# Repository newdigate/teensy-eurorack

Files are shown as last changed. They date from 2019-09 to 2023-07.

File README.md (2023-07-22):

# teensy eurorack audio shield 











Sponsored by:



**open source [hardware](hardware) and [software](https://github.com/newdigate/teensy-eurorack-software) for a 30-channel (14 in / 16 out) 16-bit analog [teensy 4.1](https://www.pjrc.com/store/teensy40.html "teensy 4.1 board") eurorack shield** 

* add peripherals to extend your [teensy 4.1](https://www.pjrc.com/store/teensy40.html "teensy 4.1 board") to interface with 
  * analog line audio (6 in / 8 out)
  * analog control voltages (8 in / 8 out: -10 to +10 volts)
  * midi in/out
  * microSD socket breakout
  * USB-A host and USB-B devices
  * 4 potentiometers, 3 encoders w/switch
* online designer [teensy eurorack audio gui](https://newdigate.github.io/teensy-eurorack-audio-gui) [^](https://github.com/newdigate/teensy-eurorack-audio-gui)

# updates 
  * 14 August 2021 : software and examples have moved to this repo [newdigate/teensy-eurorack-software](https://github.com/newdigate/teensy-eurorack-software)

# contents
* [sponsor](#sponsor)
* [specifications](#specifications)
* [license](#license)
* [open source software-stack](#open-source-software-stack)
* [build](#build)
  * [order pcbs](#order-pcbs)
  * [sourcing parts](#sourcing-parts)
    * [mouser boms](#mouser-boms)
    * [parts not on mouser boms](#parts-not-on-mouser-boms)
  * [interactive html boms online](#interactive-html-boms-online)
* [source code](#source-code)
* [improvements](#improvements)
* [printed circuit boards](#printed-circuit-boards)
  * [mainboard](#mainboard)
  * [breakout board](#breakout-board)
* [schematics](#schematics)  
* [panel design](#panel-design)  
* [assembly technical drawings](#assembly-technical-drawings)
* [youtube videos](#youtube-videos)
* [versions](#versions)
* [todo](#todo)
* [continuous-integration](#continuous-integration)
* [credits](#credits)
* [sponsored by](#sponsored-by)

# sponsor
* [patreon/teensy_eurorack](https://www.patreon.com/teensy_eurorack)
* paypal.me: [paypal.me/nicnewdigate](https://paypal.me/nicnewdigate)

# specifications
* **microcontrollers:** 
  * 600 Mhz ARM cortex m7 ( [teensy 4.1 board](https://www.pjrc.com/store/teensy41.html "teensy 4.1 board") )
* **audio:** multi-channel audio codec ( 6-in / 8-out 24-bit sound card - [CS42448](https://statics.cirrus.com/pubs/proDatasheet/CS42448_F5.pdf) )
  * *the audio codec circuit originally started as a discussion on quad audio channel outputs and a pcb design integrating teensy and cs42448 from Paul Stoffregen on [pjrc forum](https://forum.pjrc.com/threads/41371-Quad-channel-output-on-Teensy-3-6?p=138828&viewfull=1#post138828)*
* **analog control voltage ins/outs:** -10V to 10V 16bit/sample, 8 x inputs and 8 x outputs ( [ad7606](https://www.analog.com/media/en/technical-documentation/data-sheets/ad7606_7606-6_7606-4.pdf), 2x [ad5754](https://www.analog.com/media/en/technical-documentation/data-sheets/AD5724_5734_5754.pdf) )
* **display:** ST7735 128x128 16bit-color tft display
* **breakouts:** 
  * microSD card socket, 
  * USB host/device, 
  * midi in/out, 
  * knobs (4 x pots, 3 x encoders w/switch)
* **panel:** 24HP aluminium panel mounted for eurorack case
* **programability**: 
  * write arduino compatible c/c++ firmware & program using arduino/teensyduino
  * arm gnu toolchain [downloads](https://developer.arm.com/tools-and-software/open-source-software/developer-tools/gnu-toolchain/gnu-rm/downloads)
  * teensy [audio library](https://www.pjrc.com/teensy/gui/)

# license
* All artifacts are MIT license unless otherwise specified on a per file basis.

# open source software stack
* All [schematics](hardware/CIRCUITS.md) and boards are created using [Kicad](https://kicad.org/) 
* All mechanical designs are created using [FreeCAD](https://github.com/FreeCAD/FreeCAD)
* Some images have been rendered using [Blender 2.81](https://www.blender.org/)

# build
## order pcbs
* Use these gerber files to order 3 pcboards
  * the uSD-card extender should be about 0.6mm - 0.8mm thick
  * if you're using solder paste, you'll need to order the stencils of the bottom-side of main- and breakout boards.   
  
* [gerbers-breakout.zip](https://github.com/newdigate/teensy-eurorack/raw/master/hardware/gerbers/gerbers-breakout.zip)
* [gerbers-mainboard.zip](https://github.com/newdigate/teensy-eurorack/raw/master/hardware/gerbers/gerbers-mainboard.zip)
* [gerbers-uSD_extender_male.zip](https://github.com/newdigate/teensy-eurorack/raw/master/hardware/gerbers/gerbers-uSD_extender_male.zip)

## sourcing parts
Most parts are available from mouser.com - you can use the mouser BOMs below as a template to create an order. 

### mouser boms
* [mainboard](https://eu.mouser.com/ProjectManager/ProjectDetail.aspx?AccessID=e554cc1725)
* [breakoutboard](https://www.mouser.com/ProjectManager/ProjectDetail.aspx?AccessID=76e89a9e69)
### parts not on mouser boms
* panel: 
  * order from Front Panel Express: [.fpd](https://github.com/newdigate/teensy-eurorack/tree/master/hardware/panel/fpd)
    * for US: download [Front Panel Express](https://www.frontpanelexpress.com)
    * for Europe: download [Front Panel Designer](https://www.schaeffer-ag.de/en/front-panel-designer)
  * CNC your own with [FreeCad](https://www.freecadweb.org/downloads.php): [panel.FCStd](https://github.com/newdigate/teensy-eurorack/blob/master/hardware/panel/panel.FCStd) 
* mainboard:
  * 2.54mm pitch pin headers and sockets
    * J28: Eurorack power header: either male or female (2 x 8), I use female as my eurorack power (tip top) has male connectors. 
* breakout:
  * uSD card socket: [pjs008u-3000-0 yamaichi](https://octopart.com/pjs008u-3000-0-yamaichi-20649952?r=sp)
  * display: ST7735 (1.44 inch TFT LCD ST7735 SPI display module 128*128 8pin 65K color)

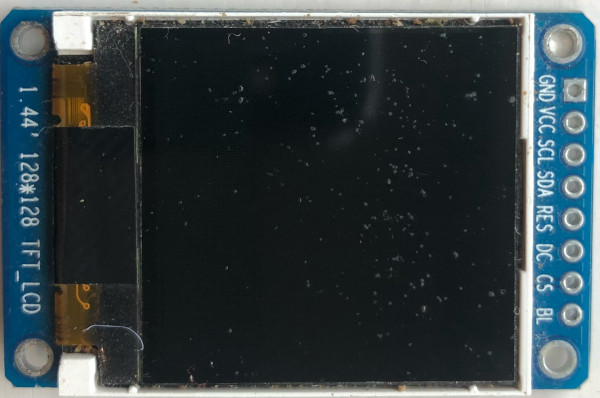
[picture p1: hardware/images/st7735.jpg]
    
    
  * 16 x thonkiconns: [PJ398SM](https://www.thonk.co.uk/shop/thonkiconn)
  * 4 x 9mm snap-in pots: [alpha-9mm-pots](https://www.thonk.co.uk/shop/alpha-9mm-pots/) - You want linear (B-series) not audio (A-series) B5K or B10K should be ideal.
  * 3 x rotary encoders w/switches: Half axis (D-shaft) rotary encoder, handle/axis length: 20mm, EC11/EC12 digital potentiometer with switch - 5Pin

**Update**: USB-A-S-X-X-VT is no longer available. [Amphenol Commercial Products GSB11111ALF](https://mou.sr/3OmC2OO) looks like it may be a good replacement.

## interactive html boms online
  * [mainboard](https://newdigate.github.io/teensy-eurorack/teensy-eurorack)
  * [breakoutboard](https://newdigate.github.io/teensy-eurorack/teensy-eurorack-breakout)

# source code
 * Teensy Audio library drivers for ad5754, ad7606 via SPI
   * [teensy-audio-ad5754-ad7606](https://github.com/newdigate/teensy-audio-ad5754-ad7606)
 * simple standard midi file reader 
   * [midi-smf-reader](https://github.com/newdigate/midi-smf-reader)
 * generic sequencer
   * [teensy-quencer](https://github.com/newdigate/teensy-quencer)
 * variable rate playback
   * [teensy-variable-playback](https://github.com/newdigate/teensy-variable-playback)
 * oscilliscope and x/y scope display components
   * [teensy-audio-libtftscope](https://github.com/newdigate/teensy-audio-libtftscope)
 * cmake macros for compiling c++ for arm cortex 
   * [teensy-cmake-macros](https://github.com/newdigate/teensy-cmake-macros)
 * Audio level and CV level meters 
   * [teensy-audio-display-components](https://github.com/newdigate/teensy-audio-display-components)

# improvements
At this point Im just focusing on finalising/polishing the current version, but there are some improvements I'd like to make at some point.
* add 4x jack sockets for analog output of knobs on breakout board. 
* use 3.5mm jack sockets (as well as standard midi din connectors) for midi in and out. 
* switch to active audio input and output circuitry, allow switchable 0dB / 12dB gain, for guitar signals.
* let me know if you're think there something else that can be improved, added, removed. 

There is a journal of my progress (its a bit out of date, sorry) - [journal.md](hardware/JOURNAL.md) 

**What you can do if you like to see progress with this project?**
* [#sponsor](#sponsor)...
* star this repository (means you need a github account - go for it!!)
* subscribe [Nic N on youtube](https://www.youtube.com/channel/UChMicDp8wUXYzBhEN-Wvb5g) 
* download kicad and freecad, clone this repo, make improvements, commit & send pull-requests, and raise issues...

# printed circuit boards
## [mainboard](hardware/boards/mainboard) 
* standard double layer printed circuit board
  * thinkness: 1.6mm  
  * minimum trace: 6 mil
  * minimum clearance: 6 mil
  * dimension: 118mm*102mm
* socket to connect teensy 4.0 board
* cs42448 audio codec 
* 3 x stereo 6.35mm TRS jack inputs
* 4 x stereo 6.35mm TRS jack outputs
* pin sockets to connect breakout board

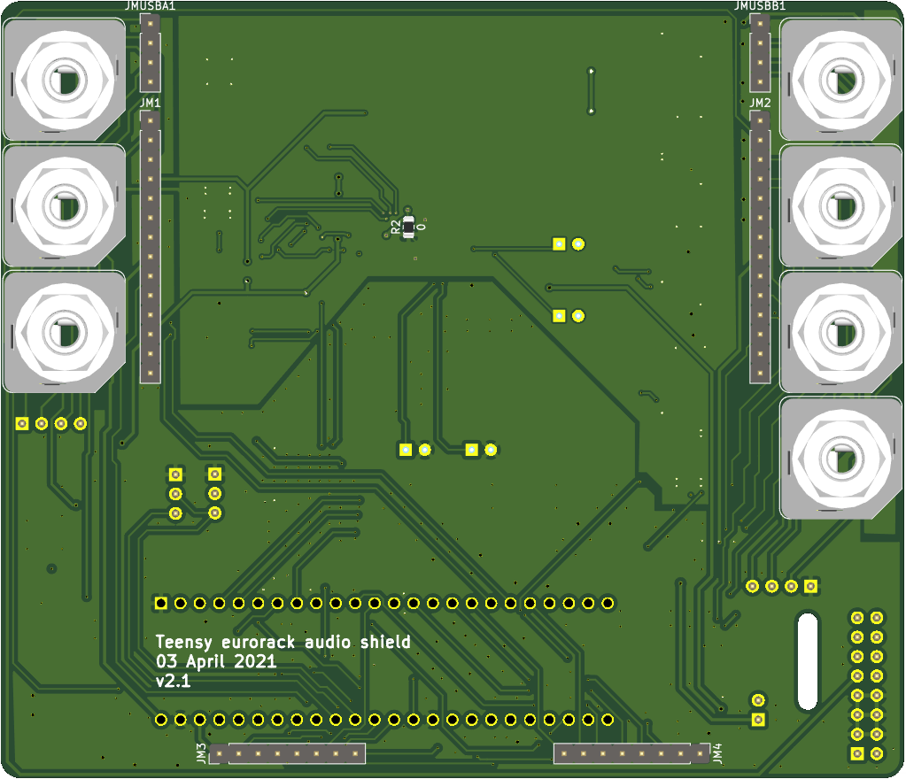
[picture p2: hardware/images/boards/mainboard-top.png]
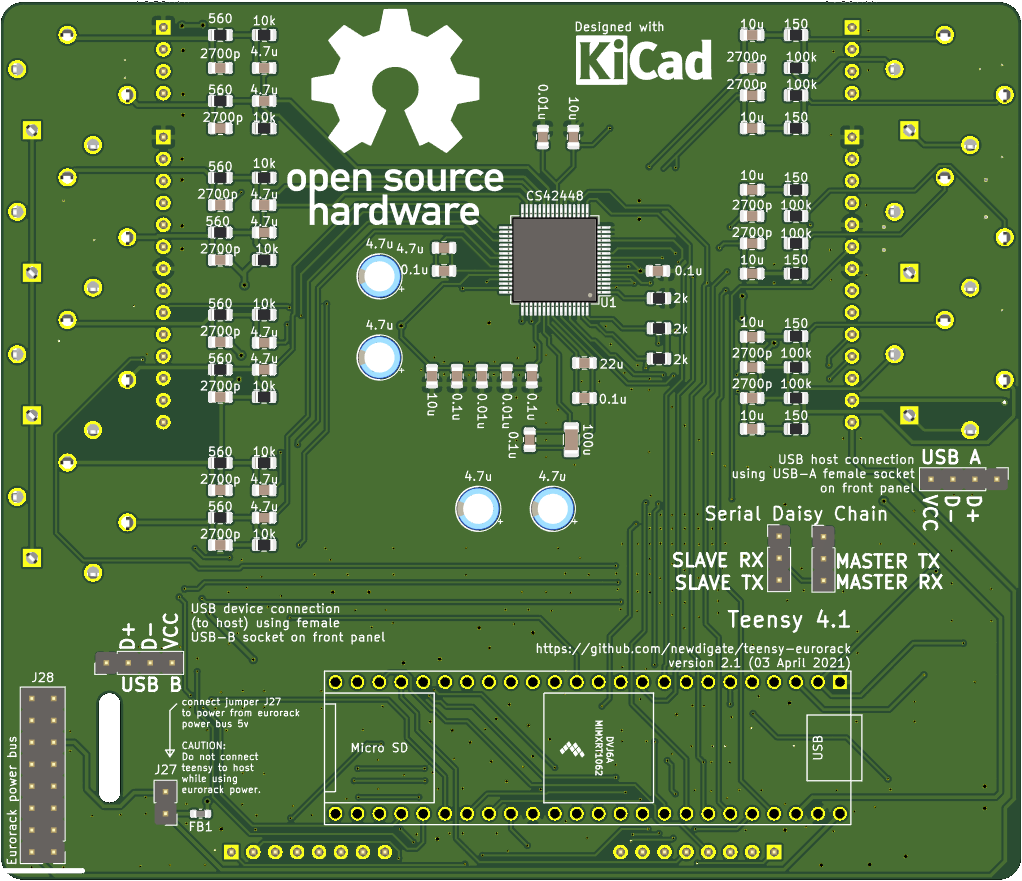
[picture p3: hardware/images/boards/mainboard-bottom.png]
  

## breakout board
* 2 layer printed circuit board
  * thinkness: 1.6mm  
  * minimum trace: 6 mil
  * minimum clearance: 6 mil
  * dimension: 110mm*111mm
* 8 x 3.5mm jack socket for analog control voltage inputs
* 8 x 3.5mm jack socket for analog control voltage outputs
* midi in/out DIN sockets
* usb device/host
  * USB-B: USB device mode
  * USB-A: USB host mode
* micro-SD card socket
* 4 x linear pots
* 3 x rotary encoders with switches 

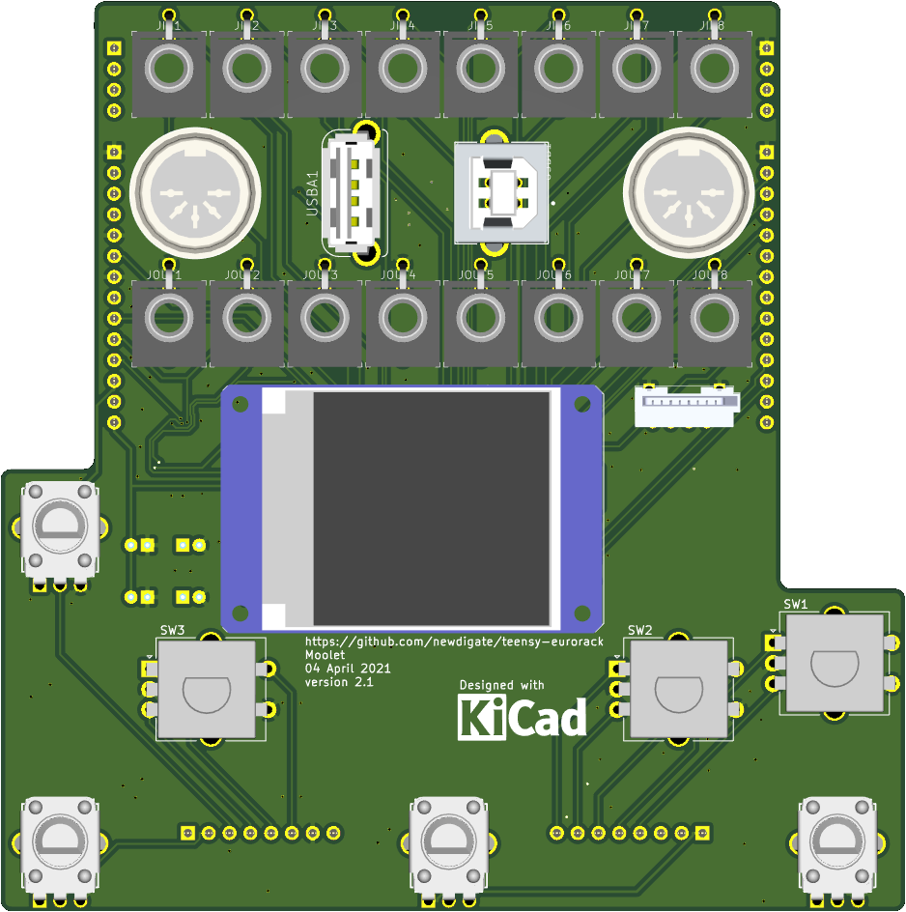
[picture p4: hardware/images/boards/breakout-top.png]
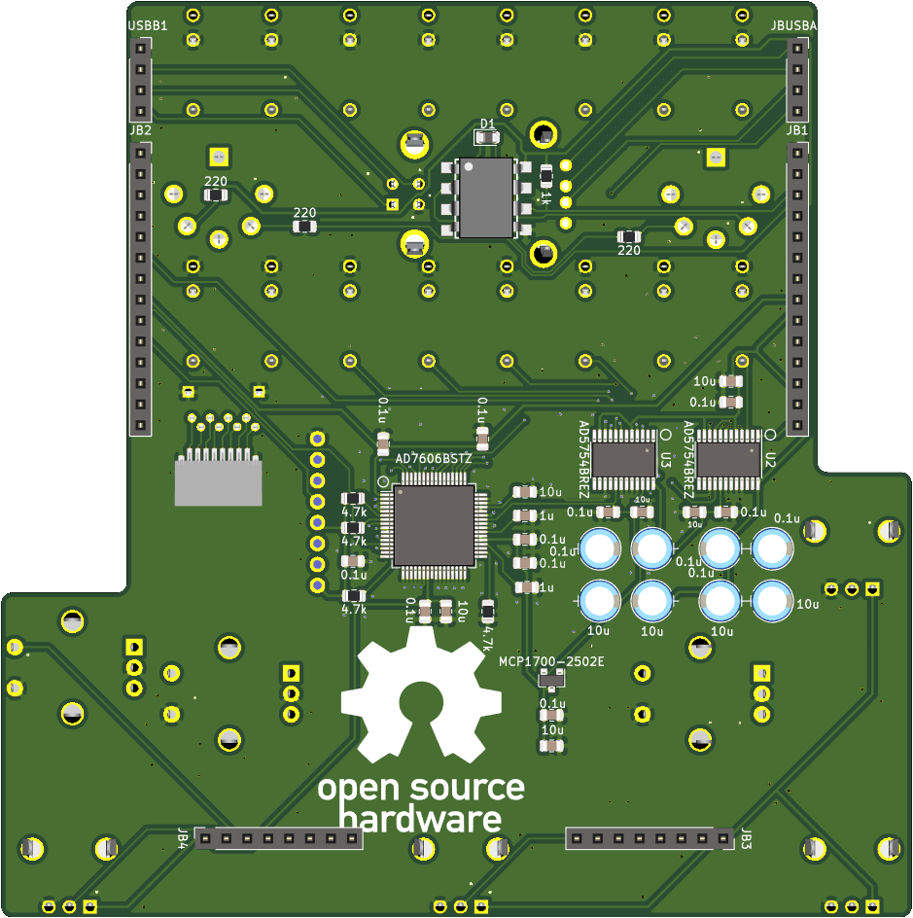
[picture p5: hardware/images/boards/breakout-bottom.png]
  

# schematics



# [panel design](hardware/panel)


# assembly technical drawings 


# youtube videos 
* [Nic N](https://www.youtube.com/channel/UChMicDp8wUXYzBhEN-Wvb5g) 
  * [youtube: Assembling custom eurorack audio shield for teensy 4.1](https://www.youtube.com/watch?v=PzaJ3Wq1Fsc)
  * [youtube: Teensy 4.0 eurorack shield design intro](https://www.youtube.com/watch?v=aNUSEszbnYU)
  * [youtube: 0v to 10v control voltage input, output and display using teensy 4.0](https://www.youtube.com/watch?v=5d5x8F7HRko)
  * [youtube: DIY assembly build - teensy 4.0 eurorack audio module](https://www.youtube.com/watch?v=oZzPgpTrEhc)
  * [youtube: assembly teensy eurorack shield](https://www.youtube.com/watch?v=Jx2KgpoT3WY)
  * [youtube: assembly timelapse](https://www.youtube.com/watch?v=s-514rDjirY)
  * [youtube: Eurorack digital audio modules powered by teensy micro-controller](https://www.youtube.com/watch?v=6zt6OF7UOTc)
  * [youtube: side-channel stereo audio separation with teensy 4.0](https://www.youtube.com/watch?v=N0IBevm4hTQ)

# versions
## v2.1 (Saturday 3 April 2021)
* **Improvement**: Mainboard: Tie LRCLK pin 20 to pin40 to sync DAC/ADC sampling w/ audio sampling
* **FIXED**: breakout: add 1k pull-up resistor to MIDI rx pin
* mainboard: silkscreen: add Kicad OpenSourceHardware logo
* breakout: silkscreen: add Kicad OpenSourceHardware logo

## v2.0.3 (Saturday 13/02/2021)
* breakout: st7735 display changed vcc, reset, backlight from 5v to 3v3.

## v2.0.2 (31/01/2021)
* Mainboard: spaced out traces as there appeared to be some interference under certain circumstances.

## v2.0.1 (27/01/2021) 
* Mainboard: add daisy chain TX/RX connector on back side to communicate between multiple boards
* Breakout board: changed back to double layer board.

## v2.0.0(b)
* Breakout board: Corrected polarity of +-12V pin headers on breakout board (ouch!!!)
* change ADC to use external 2.5v voltage reference, same as DAC voltage reference now 

## v2.0.0
* SPI: separated ADC, DAC from display: 
  * st7735 display has its own dedicated SPI - (SPI0, stays the same)
  * ADC / DAC are now sharing SPI1
* integrated ADC and DAC into teensy audio library.
* added one more ad5754 DAC for total of 8 control voltage analog output channels

## v1.9.1b
* mainboard: correction: reconnected LRCLK to codec.

## v1.9.1
* connected DAC_SCK output (pin 19) to pin 31
  * allow cable select to be asserted on minor spi data cycle after every 24 or 48 spi clock cycles, using interrupt on pin 31.
    * hopefully this will allow DMA spi transfers to AD5754 and which will make integration with teensy audio library much easier

## v1.9 
updated to teesy 4.1 and improvements to make easier to build
* updated from teensy 4.0 to teensy 4.1
* schematic, footprint and pcb clean-up 
  * replaced footprints imported from eagle with native kicad footprints
* removed atmel samd21 and gpio ICs
* replaced gpio with AD5754 (extra 4 DAC channels)
* replaced RGB encoders with regular encoders
* replaced analog-GND-to-digital-GND footprint with a 0805 zero ohm resistor footprint. (DRC checks can pass now...)
* (temporarily) removed serial TX/RX to unused eurorack power pins
  
# todo 
- [x] ~~finalize design / circuits / boards~~
- [x] ~~order~~ (v.2.1)
- [x] ~~assemble~~
- [x] ~~testing~~
  - [x] ~~CS42448 audio codec~~
    - [x] ~~Audio input~~
    - [x] ~~Audio output~~
  - [x] ~~control voltage input~~
  - [x] ~~control voltage output~~
  - [x] ~~usb host~~
  - [x] ~~usb device~~
  - [x] ~~midi in~~
  - [x] ~~midi out~~
  - [x] ~~st7735 display~~
  - [x] ~~sd card extension & adapter~~
- [ ] Document 
  - [ ] order & build process
  - [ ] software process
- [ ] Firmware

# continuous-integration 
* testing automated build and packaging 
* [github.com/pwuertz/kicad_picknplace_assistant](https://github.com/pwuertz/kicad_picknplace_assistant)
* [github.com/productize/kicad-automation-scripts](https://github.com/productize/kicad-automation-scripts)
* [InteractiveHtmlBom](https://github.com/openscopeproject/InteractiveHtmlBom) by [openscopeproject](https://github.com/openscopeproject)

# credits 
* https://github.com/dgouramanis/usdextendercable

# sponsored by
Massive thanks to these generous people who have provided support!
* Hannes Schnaitter
* Daniel Hengeveld [thedaniel on github](https://github.com/thedaniel)
* Derek Brost
* Martin Eigel
* Morgan Massens

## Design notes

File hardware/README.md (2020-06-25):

# schematics, printed circuit boards, and panels
* schematic and circuit board files for both boards [here](boards)
* panel designs [here](panel)

# circuits images
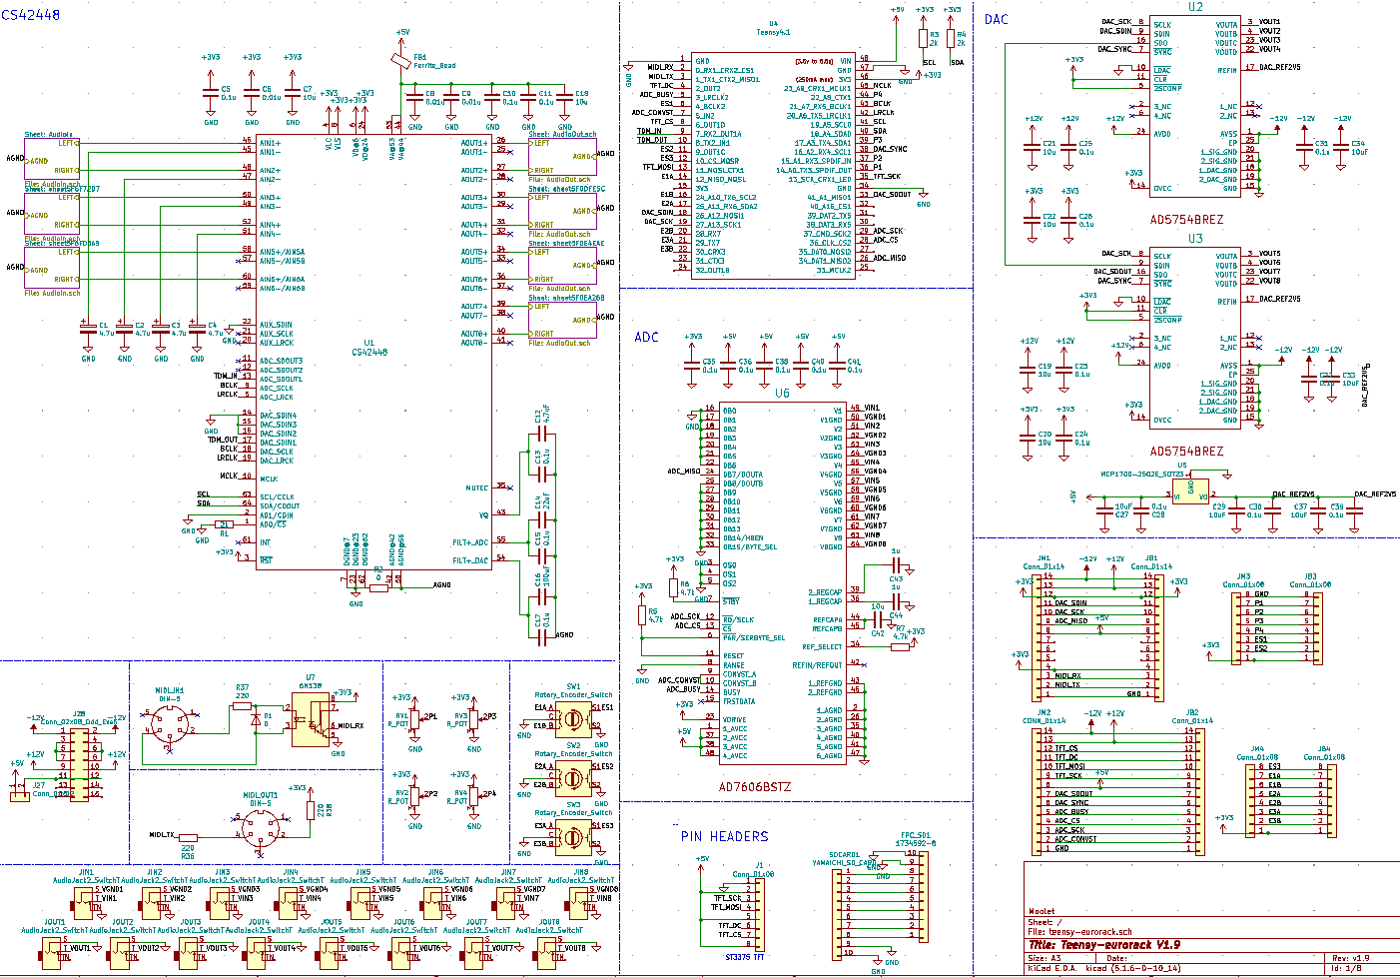
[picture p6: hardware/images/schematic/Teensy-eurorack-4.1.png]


technical drawing

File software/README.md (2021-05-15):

# [examples](examples)

# software libraries
 * simple standard midi file reader 
   * [midi-smf-reader](https://github.com/newdigate/midi-smf-reader)
 * generic sequencer
   * [teensy-quencer](https://github.com/newdigate/teensy-quencer)
 * variable rate playback
   * [teensy-variable-playback](https://github.com/newdigate/teensy-variable-playback)
 * oscilliscope and x/y scope display components
   * [teensy-audio-libtftscope](https://github.com/newdigate/teensy-audio-libtftscope)
 * Audio level and CV level meters 
   * [teensy-audio-display-components](https://github.com/newdigate/teensy-audio-display-components)
 * teensy-libcurve 
   * [teensy-libcurve](https://github.com/newdigate/teensy-libcurve)
   * draw beziers and antialiased lines

# build dependencies
* cmake macros for compiling c++ for arm cortex
  * [teensy-cmake-macros](https://github.com/newdigate/teensy-cmake-macros)

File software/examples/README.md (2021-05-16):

# software examples

* [ad5754](ad5754) 
  * [ad5754/01_write_ad5754](ad5754/01_write_ad5754) 
    * set 4 x control voltages using single ad5754 dac
  * [ad5754/02_write_both_ad5754](ad5754/02_write_both_ad5754)
    * set 8 x control voltages using both ad5754 dacs

* [audio](audio): examples using teensy audio library
  * [audio/audio_thru_with_scope](audio/audio_thru_with_scope)
    * route audio in -> audio out 
    * display audio in wave graph
  * [audio/audio_to_cv/01_audio_to_cv](audio/audio_to_cv/01_audio_to_cv) 
    * route audio input to cv output
  * [audio/cv_out/01_cv_output](audio/cv_out/01_cv_output)
    * output a sine wave on cv

* [audio/libscope](audio/libscope): examples using [teensy-audio-libtftscope](https://github.com/newdigate/teensy-audio-libtftscope) 
  * [audio/libscope/02_input_scopes](audio/libscope/02_input_scopes)
    * output sine waves on all audio and cv outputs
    * display all audio and cv inputs on a scope view
  * [audio/libscope/03_full_bandwidth](audio/libscope/03_full_bandwidth)
    * output sine waves on all audio and cv outputs
    * display all audio and cv inputs on a scope view
    * display 4 x potentiometer values on a scope view   
  * [audio/libscope/04_audio_only_full_bandwidth](audio/libscope/04_audio_only_full_bandwidth)
    * output sine waves on all audio outputs
    * display all audio inputs on a scope view
  
* codec - using [FrankBoesing/Arduino-Teensy-Codec-lib](https://github.com/FrankBoesing/Arduino-Teensy-Codec-lib)
  * [audio/codec/01_Mp3FilePlayer](audio/codec/01_Mp3FilePlayer) 
    * play .mp3 file from micro SD card
  * [audio/codec/02_Play_and_display](audio/codec/02_Play_and_display)
    * play .mp3 and .aac audio files from micro SD card
    * read mp3 tags
    * display jpeg of album cover if available
    * use rotary encoder to change directory
    * use buttons to pause/play, next, load-directory
 
* [audio/simple_scope](audio/simple_scope)
  * [audio/simple_scope/01_audiocv_scope](audio/simple_scope/01_audiocv_scope)
    * display graph of incoming audio and cv (no dependencies) 
  * [audio/simple_scope/02_simple_cv_scope](audio/simple_scope/02_simple_cv_scope)
    * display graph of incoming cv (no dependencies)

* [graphics](graphics)
  * [graphics/00_graphicstest](graphics/00_graphicstest)
    * Adafruit graphics test adapted for teensy-eurorack parameters
  * [graphics/01_heart](graphics/01_heart)
    * Draw anti-aliased bezier curves (using [newdigate/teensy-libcurve](https://github.com/newdigate/teensy-libcurve))

* [knobs](knobs)
  * [knobs/just_encoders](knobs/just_encoders)
    * read values of 3 rotary encoders
    * output changes on serial monitor
  * [knobs/just_encoders_and_display](knobs/just_encoders_and_display)
    * read values of 3 rotary encoders
    * output changes on serial monitor
    * initialize st7735 and display some text
  
[midi](midi)
 * [midi/01_MidiIn_display](midi/01_MidiIn_display)
 * [midi/02_MidiOut](midi/02_MidiOut)

## builds






































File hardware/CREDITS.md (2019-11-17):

3d step files used:
https://grabcad.com/library/teensy-4-0-1#!

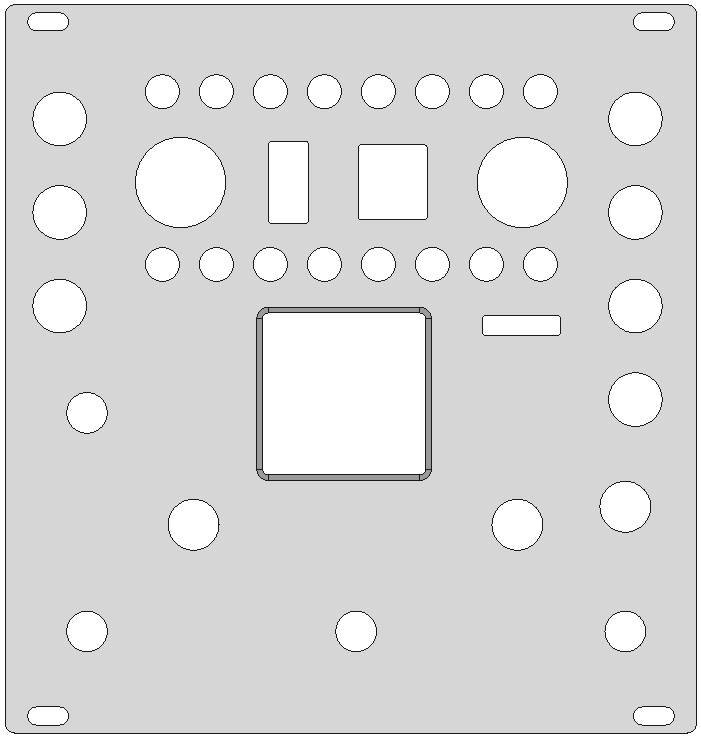
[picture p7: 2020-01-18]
hardware/panel/images/panel-front.png

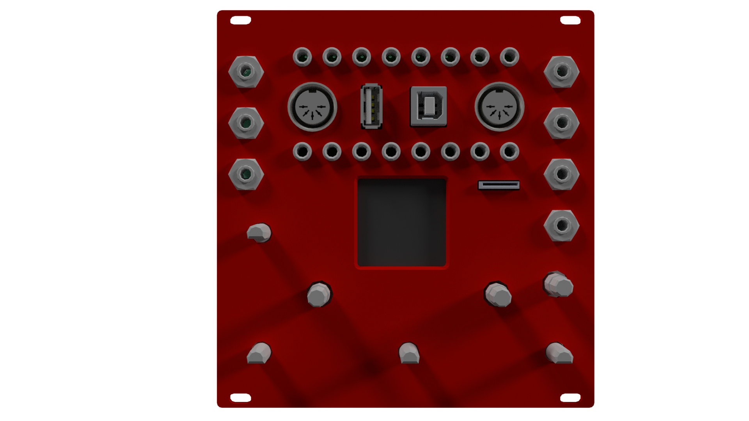
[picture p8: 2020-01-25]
hardware/images/kryonos.png

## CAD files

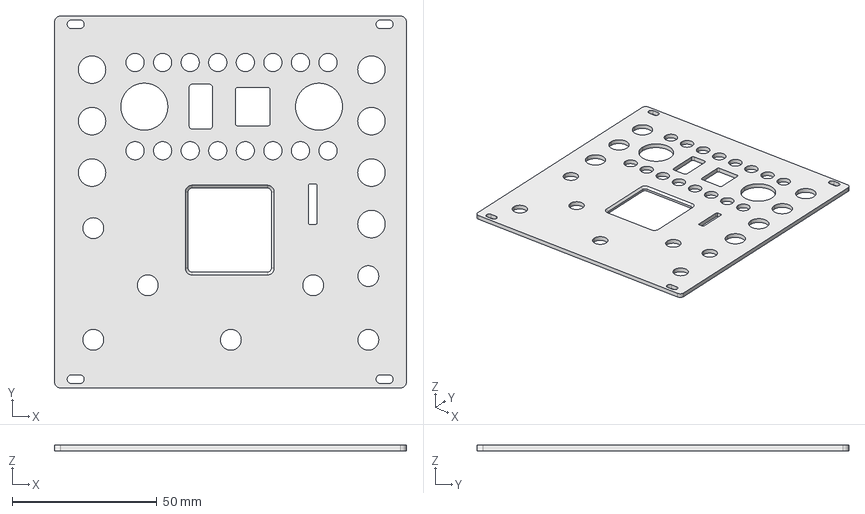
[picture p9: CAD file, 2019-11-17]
hardware/Assembly.FCStd
121.6 x 128.4 x 2.00 mm

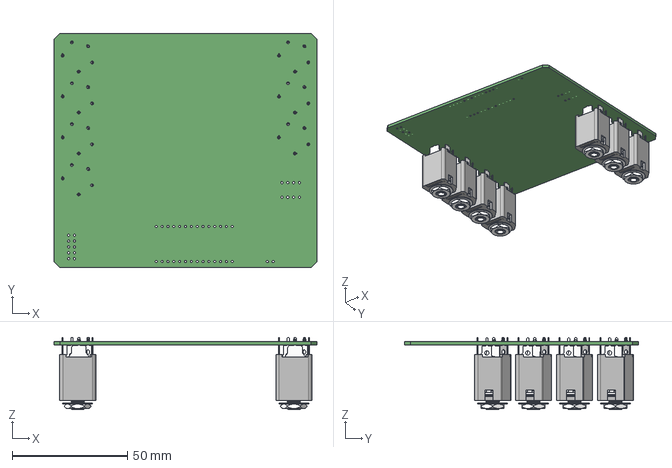
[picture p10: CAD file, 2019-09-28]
hardware/boards/mainboard/Mainboard.step
114.3 x 101.6 x 31.4 mm

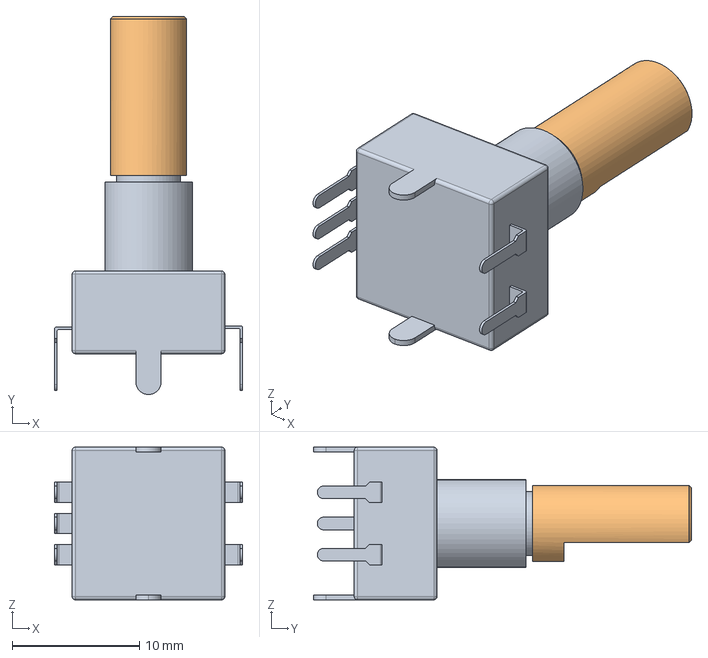
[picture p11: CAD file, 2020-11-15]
hardware/boards/3d/RotaryEncoder_Alps_EC11E-Switch_Vertical_H20mm.step
14.8 x 29.7 x 12.0 mm

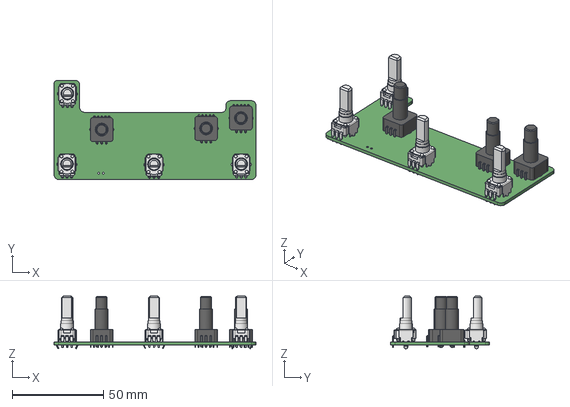
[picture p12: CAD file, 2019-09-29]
hardware/boards/knobs-controller/knobs.step
110.5 x 54.3 x 28.8 mm

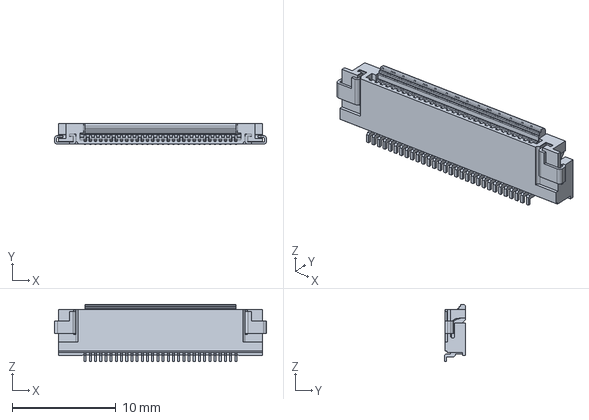
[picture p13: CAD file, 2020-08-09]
hardware/boards/3d/Molex-52892-3033.step
20.4 x 2.04 x 5.50 mm

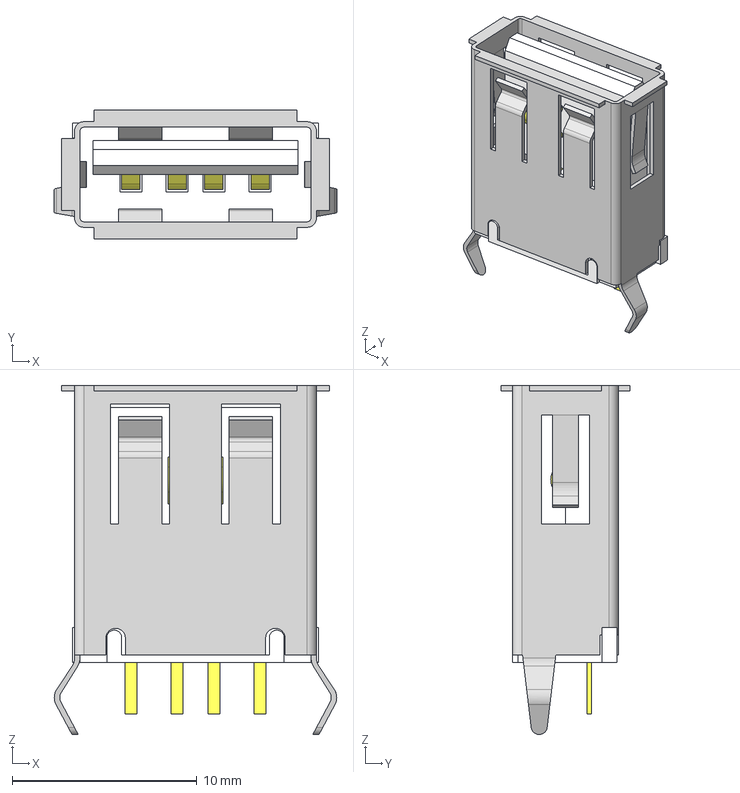
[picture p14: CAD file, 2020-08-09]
hardware/boards/3d/USB-A-S-S-W-VT.stp
15.3 x 7.00 x 18.9 mm
_USB-A-S-VT_S
_USB-A-S-W-VT_B
_USB-A-S-VT_P

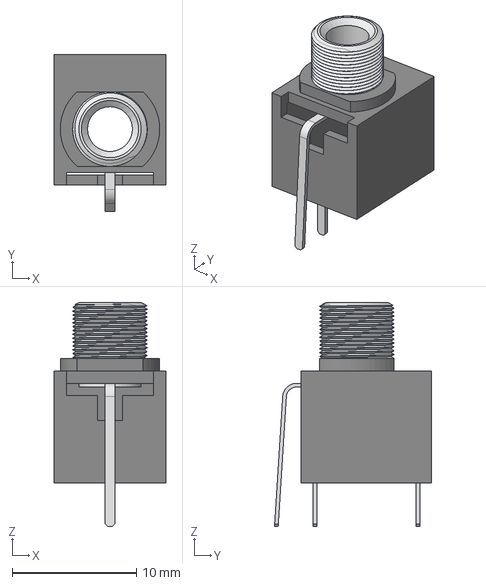
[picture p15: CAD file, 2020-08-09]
hardware/boards/3d/PJ301M-12 Thonkiconn v0.2.stp
9.00 x 12.6 x 18.0 mm

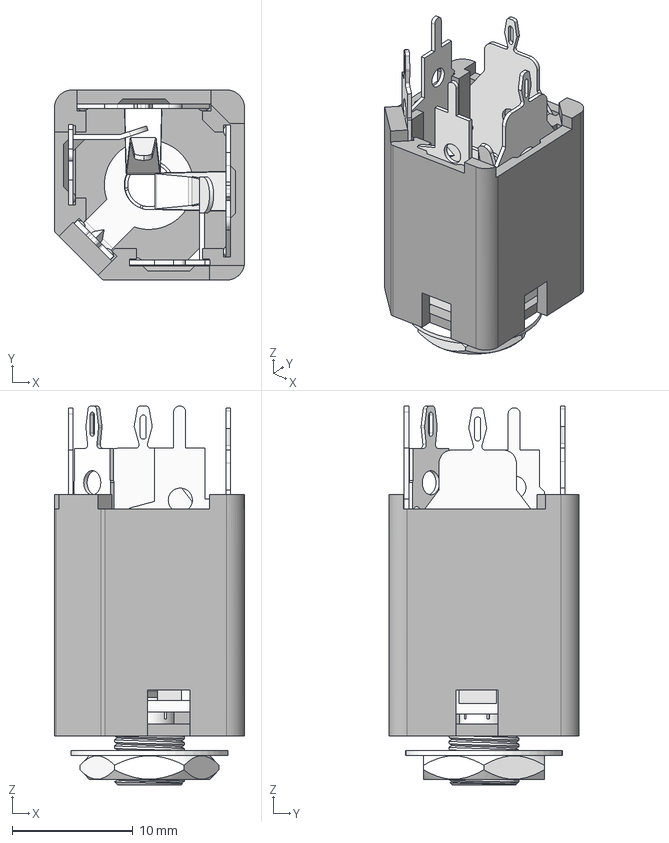
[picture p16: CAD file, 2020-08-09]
hardware/boards/3d/ACJS-MV35-5.step
15.8 x 15.8 x 31.4 mm

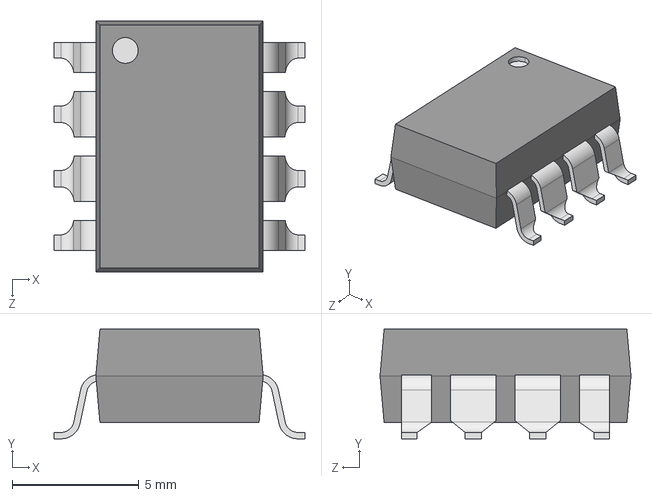
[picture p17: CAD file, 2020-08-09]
hardware/boards/3d/User Library-8-pin-DIP_GW_HCPL-4200-300E.STEP
9.90 x 4.33 x 9.90 mm

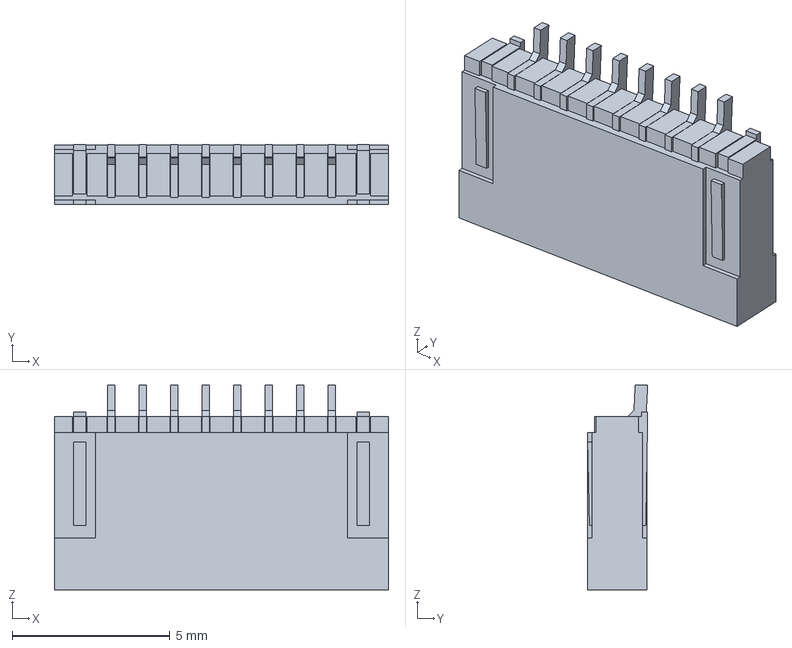
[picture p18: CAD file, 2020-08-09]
hardware/boards/3d/HFW8R-1STE1LF.stp
10.6 x 1.92 x 6.50 mm

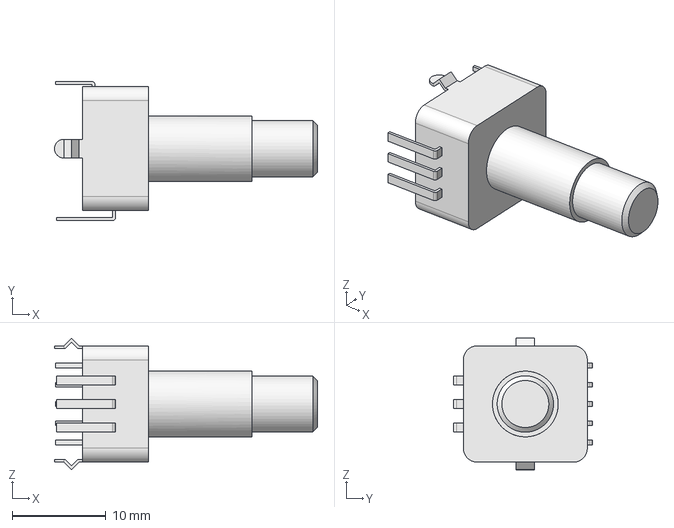
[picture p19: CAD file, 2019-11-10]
hardware/boards/3d/Bourns PEL12T4225S-S1024-white.step
28.0 x 14.8 x 14.0 mm

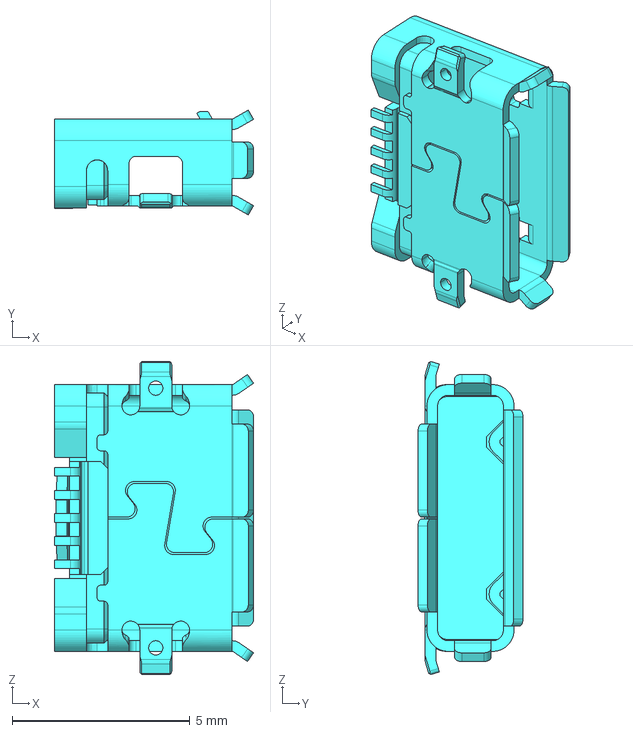
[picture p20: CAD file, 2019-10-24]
hardware/boards/3d/ZX62-AB-5PA.stp
5.60 x 2.95 x 8.80 mm

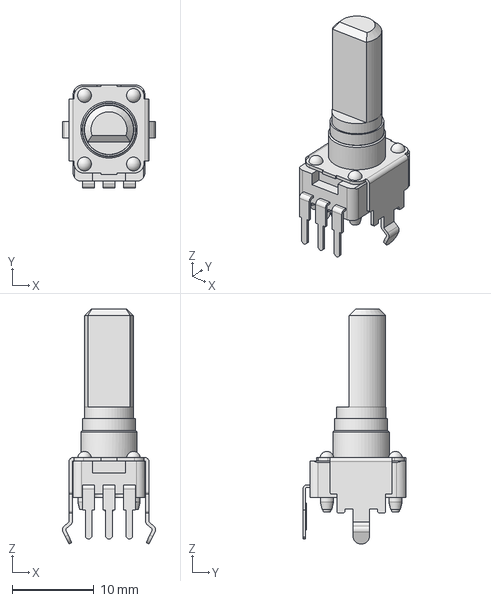
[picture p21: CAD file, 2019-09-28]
hardware/boards/3d/Panasonic_EVU-F2MFL3D14.step
11.4 x 12.7 x 28.8 mm

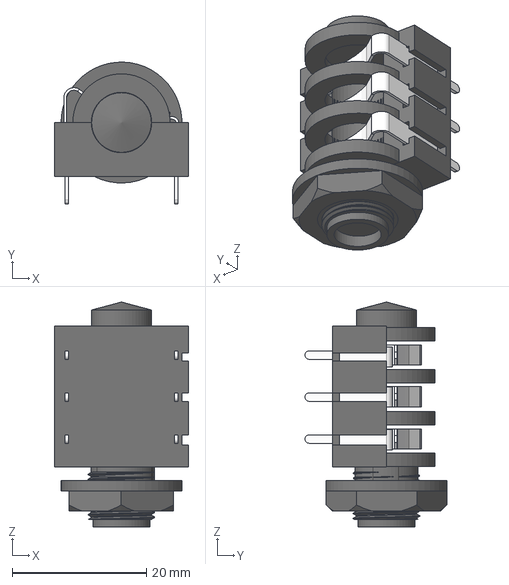
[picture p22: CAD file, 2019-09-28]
hardware/boards/3d/ACJS-PH v28.step
20.0 x 21.1 x 33.5 mm
JackConnector-female-6.35-entrance-threaded
nut

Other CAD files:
hardware/panel/3d/panel.step
hardware/panel/fpd/panel.stp
hardware/boards/3d/Yamaichi - PJS008U-3000-0.step
hardware/boards/3d/MIDI DIN 5 v7.step
hardware/boards/3d/1734592-8.stp
hardware/boards/3d/Bourns PEL12T4225S-S1024.step
hardware/boards/3d/CS42448-CQZ.step
hardware/boards/3d/Conn_Wurth Electronics_61400413321.step
hardware/boards/3d/conn_JST_S4B-PH-SM4-TB(LF)(SN).step
hardware/boards/3d/ili7735 v6.step
hardware/panel/panel.FCStd

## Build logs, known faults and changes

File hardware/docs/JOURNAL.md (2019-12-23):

# Journal

## 2 december 2019
mainboard v1.5 and knobs v1.5 pcb arrived from jlcpcb. 

while assembling mainboard v1.5. my heat gun died before i could start baking. 

i’m waiting for a new heat gun to arrive today hopefully. i received a new heat gun replacement yesterday but unfortunately i got the same s/e sensor error. so i ordered a whole new heat gun station. 
i have solder pasted and placed all components on the top side and i’m ready and waiting for my new heat gun station. 

new heat gun station arrived today. i will start backing tomorrow. 

## Tuesday 3 November 2019
assembled my main board today. there are a few solder bridges in the cs42448 chip - needs a little work. 
quite happy with my new hot air gun. although there were initial teething problems. i was switching the solder iron on without realising it was the soldering iron switch not the heat gun switch. 

## Monday 16 November 2019
after assemblying and some refluxing. mainboard sound card audio out was tested successfully.

knobs controller 
* v1.5 assembled
* has issue with uart tx/rx not connected to microcontroller. 
* v1.6 ordered. 

mainboard v1.5 assembled - 
* pull up resistor for adc reset no longer connected to microcontroller. 
* no free pins on teensy, so i introduced i2c gpio breakout ic. freed up 4 pins on the teensy - so i reconnected the ad reset pin. 
* i also introduced a different eurorack power connector 16 pins instead of 10. i have wired the extra pins to the a serial port on the back side of the teensy 4. i have added jumper switches to enable slave and master modes, if you need to crossover tx/rx.  also added a jumper setting for the 5v source to switch between eurorack 5v and 5v via regulator via eurorack 12v. the power regulator makes a very high pitch noise when i connect the input to 12v.

top breakout board

* unfortunate the cv input is not entirely working so far, i seem to just get 0v values. 
* i will test the cv output soon. 
* i am thinking of combining the knobs controller and the top breakout board. 

top breakout test rig. 
i’d like to build a breakout to test top breakout. using the mainboard is very clumsy and i don’t have access to the signals i need to inspect. 

## tuesday 17 december 2019
created test rig for top breakout board and a jig to help solder the pins on the underside of the teensy. ordered from jlcpcb. 

## 22 december 2019
made a few updates to top breakout board. v1.6: rotated display 90 degrees. added test points for various traces. removed connection from dac to miso as it should not be needed and could be causing interference with adc. improved annotation. ordered green board from jlc.

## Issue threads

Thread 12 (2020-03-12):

Available for sale ?

0mars, 2020-03-12:
Is it available for sale as a module ? looks interesting

newdigate, 2020-03-12:
Hopefully soon... Im working on building some documentation to help with the build, if you wanted to try to build yourself...
I'd like to start to sell kits for DIY assembly and fully assembled modules soon.

newdigate, 2020-03-12:
Would you be interested joining a mailing list for those interested when getting notified about when this module is available for purchase as a kit, assembled?

nicolasdf1, 2020-03-12:
Yes! Please add me to a mailing list. Thanks for this project and your
dedication to creating documentation and also offering it as DIY.
The power of the DIY community is unmeasureable.
All the best,
Nicolas Fellas

On Thu, Mar 12, 2020 at 10:14 AM Nic Newdigate <notifications@github.com>
wrote:

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

jonasfehr, 2020-03-12:
Hi, please add me to the mailing list too...
Kind regards
Jonas

fehrjonas at gmail com

jonasfehr, 2020-03-12:
I have had good success, having china soldering all SMD parts. Maybe this could be an option for the kit versions?

newdigate, 2020-07-23:
@simonredfern added to the list...

https://github.com/simonredfern

zazze, 2020-07-24:
Yes, please add me to the mailing list!
I am definitely interested.
Thank you for sharing your work!
Best wishes
Johan Zetterqvist
    Den torsdag 12 mars 2020 10:14:48 CET, Nic Newdigate <notifications@github.com> skrev:

Would you be interested joining a mailing list for those interested when getting notified about when this module is available for purchase as a kit, assembled?

—
You are receiving this because you are subscribed to this thread.
Reply to this email directly, view it on GitHub, or unsubscribe.

newdigate, 2020-07-24:
2 done....

5 to go....

hang in there guys...!!!! I need to test my current revision 1.9 and Im also working on 1.9.1 which will hopefully help us to integrate the ad5754 into the teensy audio library...

erwincoumans, 2020-07-25:
nice, please sign me up for diy kit, erwin.coumans at gmail.com

newdigate, 2020-07-25:
added...

tompilot, 2021-02-11:
Hi, this looks really cool! +1 for the mailing list please.
Do you have any experience with noise issues? I have an Audio Shield + Teensy 4.1 here, connected the line in/outs to Eurorack and i get really a LOT of noise and hiss. Power supply is coming from Eurorack also. I wonder how it performs with different (better) ADC/DACs and on a real PCB instead of breadboard.

newdigate, 2021-02-15:
Hi Tom.

Breadboards are very good for audio, they are usually quite intermittent, you can get them to work, but they are very fragile, I experienced this first hand. You should download Kicad and see if you can build a circuit and a pcboard.

Other thing is that I assume your not sending control voltage into the audio card. CV is +- 12v (24 volts) and line audio is +-1V so you will either kill your audio codec or you'll get clipping, Im assuming you already know this..

I doubt either of these things will cause a hiss thou.

What you really want to do is hook your MCLK, BCLK, LRCLK and TX to a logic analyser like Saleae and check that it can decode and that you are not sending junk to your audio codec.

Also make sure that vcc is not too far above the i2s levels, when vcc is higher that signals, it becomes more suseptable to noise.

newdigate, 2021-02-15:
I think your hiss is coming because your audio levels are really low and youre amplifying the shit out of it? That sounds like a source of hiss..

newdigate, 2021-02-15:
@tompilot if you like you can continue this conversation here 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

tompilot, 2021-02-26:
Thank you Nic for your detailed answer! I have done some experimentation and finally found some sort of "solution".

My current DSP approach is a lot about FIR filtering and convolution of long impulse responses (which is all quite CPU hungry). I figured out that when using long IRs with the Teensy Audio Lib the I2S clock starts to jitter (Teensy is I2S master). Also, some of the noise came from putting the power supply through the breadboard.

To get a clean environment i did:
- Use another audio shield (WM8731) with crystal and **use I2S Slave mode**, so that the crystal creates the clock signal - not the Teensy. I also noticed changes in the noise when other CPU- or timer consuming tasks are running, in my case printing on a display and using encoders. Probably the SGT5000 codec would also be doing fine in slave mode, but the PJRC Audio shield does not support a crystal on it.
- Solder the line input on the development board instead of going through the breadboard (blocking cap and two resistors in case of WM8731). Having it on the breadboard was very sensitive to picking up noise.
- Solder the power supply directly to the Teensy. I am using the 5V line of my Rack as the power.
- In general: Disable the 5V supply from the USB programming cable by cutting a trace on the Teensy (you should never use two power sources at once)

By now, i only have the I2S and i2c lines going over the breadboard, which does not seem to have an effect.
Will switch over to gitter now, but i just wanted to give my reply here for completeness :-)

newdigate, 2021-03-14:
Just a quick update - if you want to follow the project and get updates, priority pre-orders, discounts, pcbs -  please consider supporting this project in patreon: https://www.patreon.com/teensy_eurorack

Thanks :)

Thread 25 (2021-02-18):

Quick question

thedaniel, 2021-02-18:
Sorry, I looked around online for a twitter handle or email, and didn't find something right away so I figured I'd open an issue. I have a need for something like your project to prototype a sampler module (since i apparently fried my 1010 euroshield) and since you mention you're coming along with v2, I just wanted to check if you think I should wait for you to verify your v2 circuit, or build the one that's described in the repo today. This is in no way meant to be pressure on you to provide a date or to hurry you, just curious if I'll be happy with v1 for prototyping if I start getting PCBs and components ordered or if you reckon it's worth the wait for v2. You can reply here if you like or drop me a line at danielwh@gmail.com - or ignore and keep working on your own time :)

newdigate, 2021-02-18:
hi. v2 is almost done. although i’ve been saying that for a while. i’m pretty sure this model is good, i’ve fixed the last outstanding issue, hopefully i haven’t created any new issues. latest breakout board arrives on monday so i should be able to assemble it and test the vitals by end of next week. probably worthwhile to wait a week. if you like you can order the pcb in the meantime. pcbs are cheap enough. the best thing is to learn to reuse the ics then your only cost is pcb and they’re very cheap from jlcpcb

newdigate, 2021-02-18:
get started with parts. let me know if you have a hard time sourcing any parts....

thedaniel, 2021-02-18:
Perfect - this weekend I want to make up a bunch of BOMs on Mouser for my various oustanding projects and make one big order, and I will start one for this as well.

thedaniel, 2021-02-19:
Is there a handy text / spreadsheet BOM or should I just go through the schematic?

newdigate, 2021-02-19:
i use interactiveBOM and i generate it every time i push my commit to github. in github actions under the repo their should be 2 sets of builds, o e for mainboard and one for breakout board. go to the latest build and download the artifacts. inside the strifacr you will find the interactive BOM html file.

newdigate, 2021-02-19:
having said that, there might be generic part descriptions. let me know if you need any specifics.

thedaniel, 2021-02-24:
I think without repo permissions I can't see or download build artifacts, unless I just can't find it in the UI (or maybe it's API-only)

newdigate, 2021-02-24:
Ah, I didnt realize that... always thought everybody could access those. You could fork the repo, then you're artifacts would be available under your folked repo..I couldn't seem to make the artifacts public on github for some reason.

 I have created this release as a work around in the meantime: https://github.com/newdigate/teensy-eurorack/releases/tag/v2.0-beta - it should have the interactive BOMs for each board.

Also there is a message on patreon about the bypass caps being slightly too long. 10mm bypass caps (the aluminium through hole ones, 8 in total, need to be slightly shorter than 10mm so that mechanical collisions don't occur between the two boards)

thedaniel, 2021-02-24:
nice thanks! i think i might be able to get the build artifacts via the API
since it's a public repo but this is much easier, thanks

On Wed, Feb 24, 2021 at 7:20 PM Nic Newdigate <notifications@github.com>
wrote:

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

--
Daniel Hengeveld
https://danielhengeveld.com/

newdigate, 2021-02-24:
RE: front panel - its not on the BOM...
There is an .fpd file in the repo which you can submit online to schaeffer-ag (as I assume you are in europe - there is a different company in US) and they will send. You can load, submit order using their front panel designer software, https://www.schaeffer-ag.de/en/front-panel-designer

You can also CNC into 2mm aluminium or 2.5mm perspex if you like gcode.

Or you can order aluminium pcb from JLCPCB, I havent tried this yet, Im hoping its cheaper than shaeffer-ag (usually about 33 euros or so per faceplate from shaeffer)

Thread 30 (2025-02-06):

Daisy

aolney, 2025-02-06:
First off, I'm impressed by the foresight and ambition of your project, which has been been echoed recently by Vinia and Disting NT.

I was wondering what your thoughts were on extending the project with Daisy rather than Teensy, the main purpose being the expanded memory that Daisy has, which should be much better for reverbs/delays/looping.

Specifically, is Daisy something you considered, and if so, why did you decide against it?

My sense is that the switch would be more an effort on the software side than the hardware side - am I wrong?

newdigate, 2025-02-08:
Hi Andrew. I didn’t consider electrosmith daisy. 🌼 yep I imaging the
software stack will need to be redone and also the pin out. I think daisy
only appeared in 2020?

I don’t know much about daisy, I always wanted a Daisy, love the idea of
learning rust, although I never got that far, so I don’t really know the
daisy eco system.

How much memory does the daisy have? I have 16 mb psram on my teensy 4.1.
More ram is very appealing to me.

On Thu, 6 Feb 2025 at 21:12, Andrew M Olney ***@***.***>
wrote:

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

pknoot, 2025-02-08:
64MB

https://daisy.nyc3.cdn.digitaloceanspaces.com/products/seed/Daisy_Seed_datasheet.pdf

aolney, 2025-02-08:
Thanks @pknoot :)

The Daisy has quite a bit and is widely used in commercial releases of effects modules, e.g. [the QuBit Stardust](https://www.qubitelectronix.com/shop/p/stardust) with minutes of multi channel looping.

Some of the interesting issues that come up in comparing Teensy 4.1 to Daisy

- Teensy has twice the L1 cache (32K vs 16K)
- Teensy has a higher clock speed (600 vs 480)
- Daisy has more ~4-8x more RAM (64 MB vs 8/16MB)

For a device that attempts to be an ER-301-style sound computer, the question (for me at least) is then whether processor performance outweighs RAM (so Teensy is better) or whether Daisy's processor is "good enough" and so RAM is more important.

@newdigate 's project, Vinia, and Disting NT are all success cases for a Teensy-based sound computer (in NT's case, perhaps I should say Teensy-adjacent).

I'm not aware of a similar success case for Daisy, so I wonder if it's either simply because it hasn't been done yet, or is it because there is some subtle aspect of the Daisy platform that makes it less suitable for supporting many simultaneous channels of multi-algorithm processing.

newdigate, 2025-02-08:
The nice part of this project is the 8in/8out +10/-10v precision adc and
dac paired together on an spi bus configured on  a wierd 48 bit cycle and
clocked with the audio codec at 44k100. The rest is pretty straightforward

On Sat, 8 Feb 2025 at 15:56, Andrew M Olney ***@***.***>
wrote:

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

aolney, 2025-02-09:
Thanks @newdigate . FWIW I've looked into this some more and decided that the RAM on the Daisy makes it the most suitable for my use case of these two options, though designing a custom board that combined both their strengths would be best.

I'm going to mark this as closed but feel free to reopen

aolney, 2025-02-12:
[Here's an M7 with 256MB RAM](https://www.nxp.com/design/design-center/development-boards-and-designs/MIMXRT1060-EVKB); I think this combines the strengths of Teensy and Daisy at the hardware level.

The multichannel audio card on that page makes me think disting nt is based on this platform.

Closed 2025-02-09.

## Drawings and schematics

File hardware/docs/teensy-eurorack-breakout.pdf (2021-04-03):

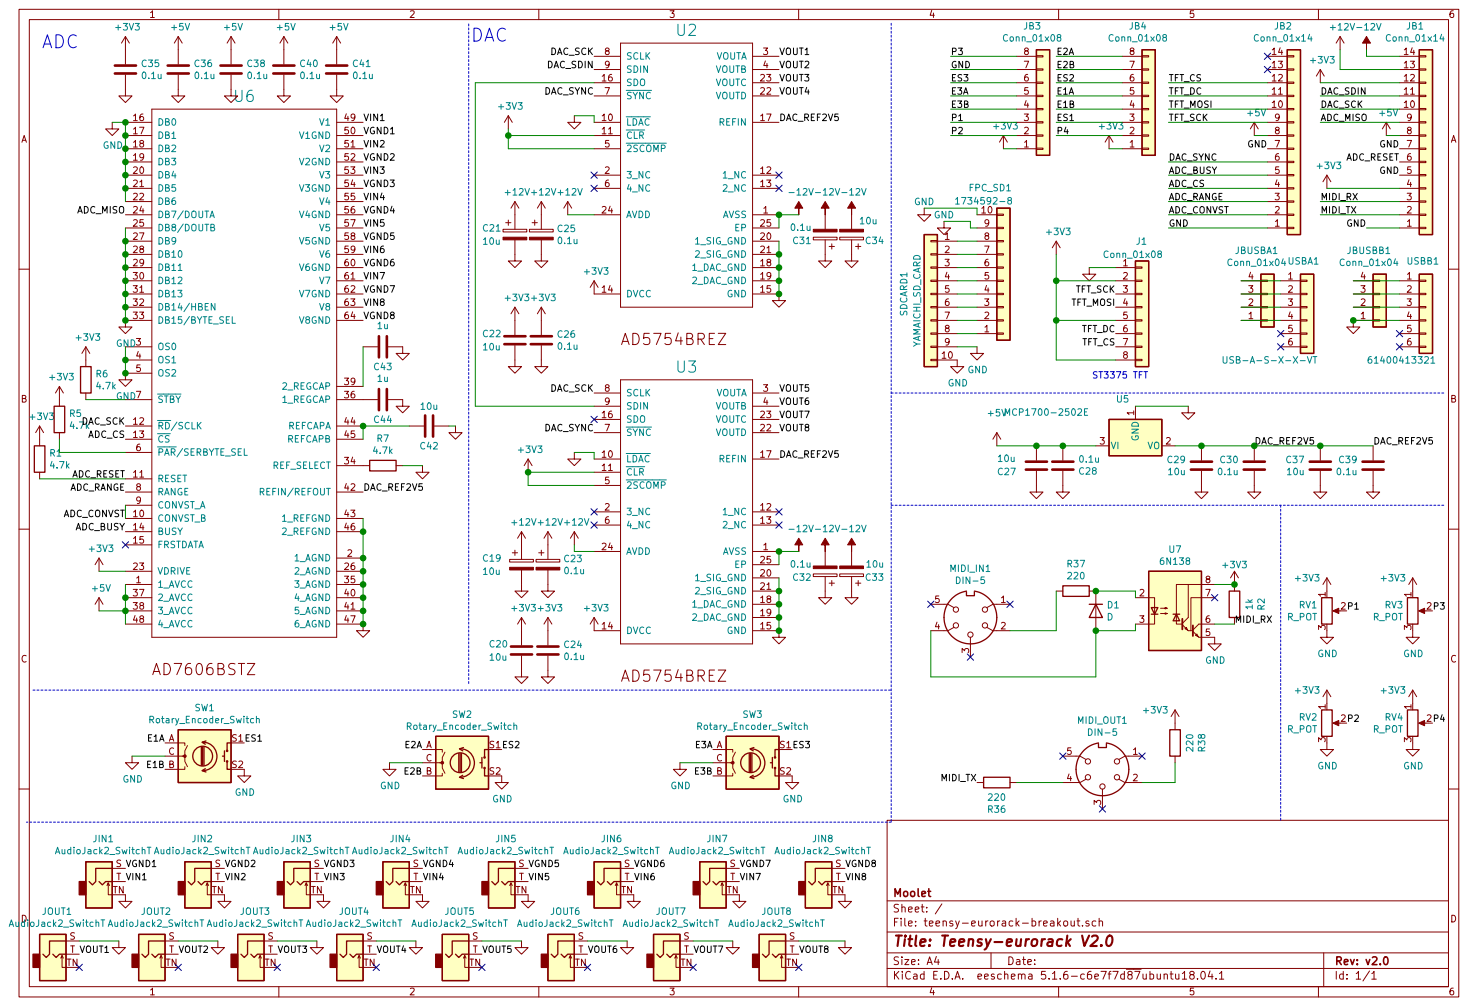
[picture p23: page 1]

File: teensy-eurorack-breakout.sch Sheet: / Moolet C23

Id: 1/1 Title: Teensy-eurorack V2.0

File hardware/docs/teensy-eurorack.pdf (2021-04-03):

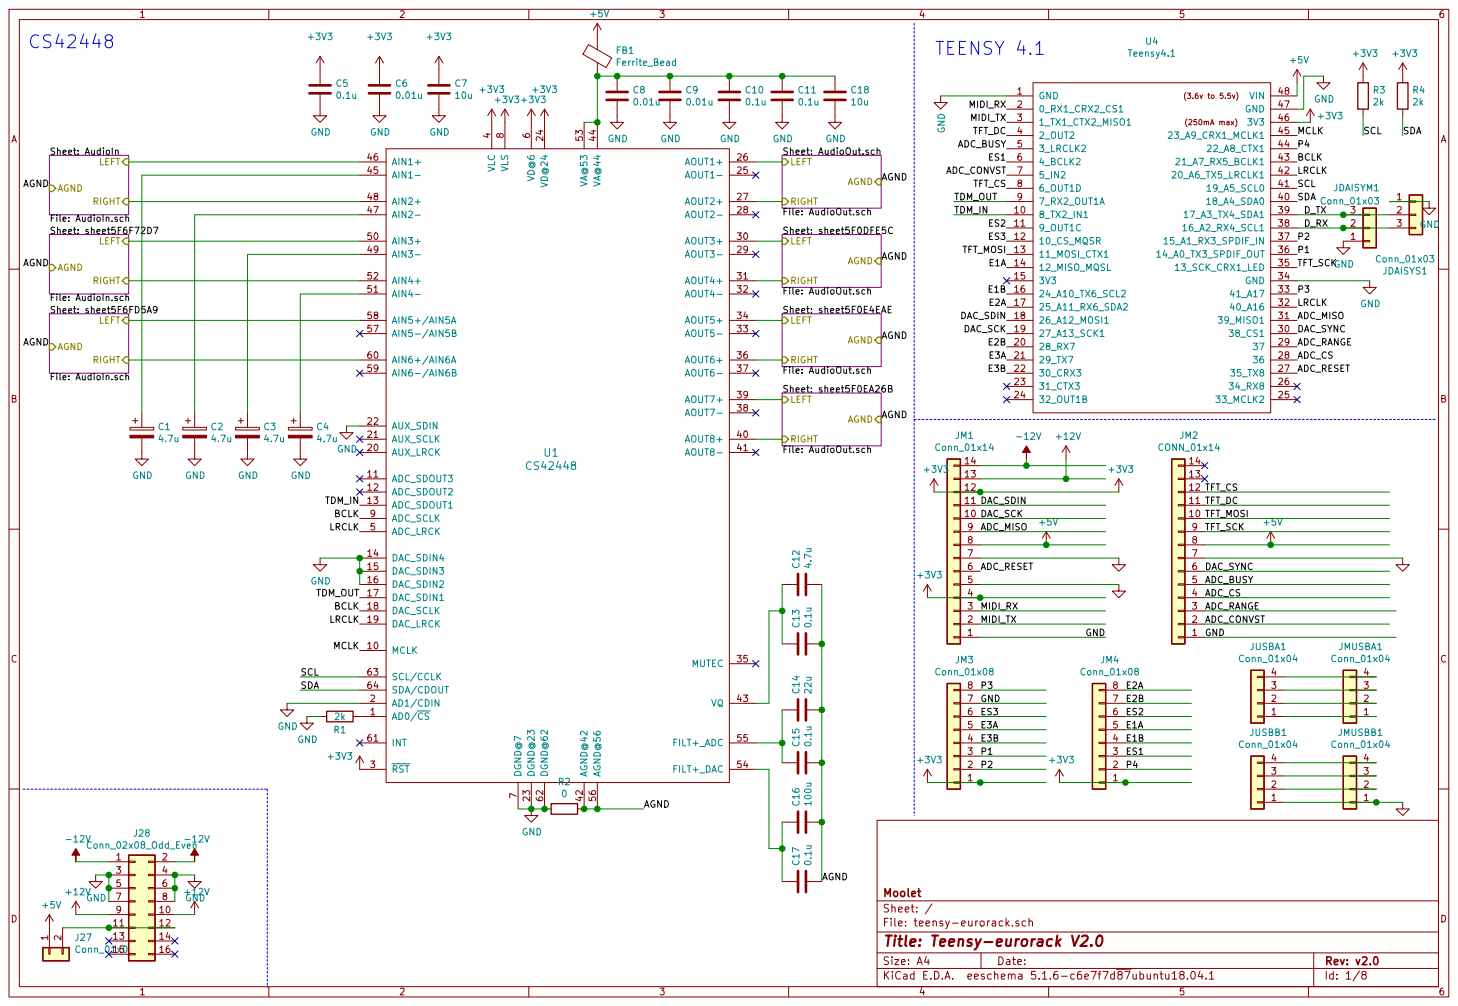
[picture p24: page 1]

4 AOUT8+ 40 AOUT8- 41 AGND@42 42 VQ 43 VA@44 44 AIN1- 45 AIN1+ 46 AIN2- 47 AIN2+ 48 AIN3- 49 ADC_LRCK 5 AIN3+ 50 AIN4- 51 AIN4+ 52 VA@53 53 FILT+_DAC 54 FILT+_ADC 55 AGND@56 56 AIN5-/AIN5B 57 AIN5+/AIN5A 58 AIN6-/AIN6B 59 VD@6

Sheet: AudioIn File: AudioIn.sch
LEFT RIGHT AGND

Sheet: AudioOut.sch File: AudioOut.sch

Sheet: sheet5F6F72D7 File: AudioIn.sch

9_OUT1C 11 | 2 | 3
10_CS_MQSR 12 | 1

Sheet: sheet5F6FD5A9 File: AudioIn.sch

File: teensy-eurorack.sch Sheet: / Moolet

Id: 1/8 Title: Teensy-eurorack V2.0

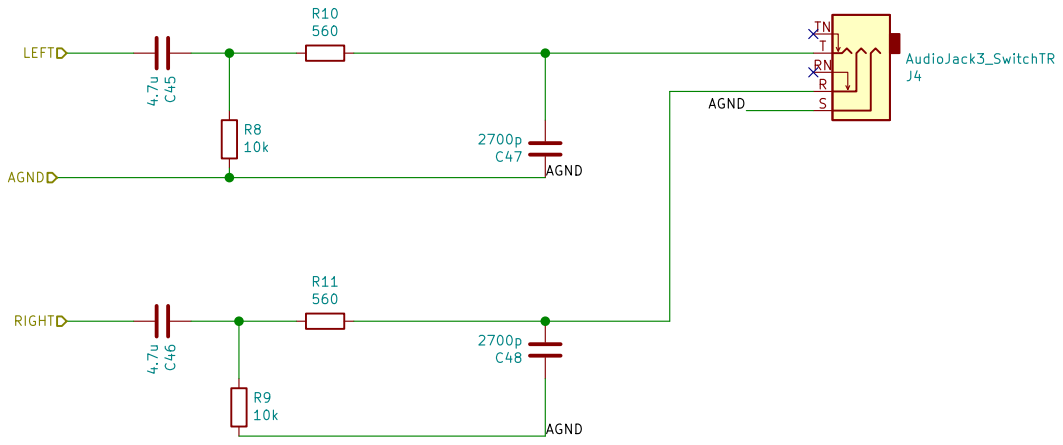
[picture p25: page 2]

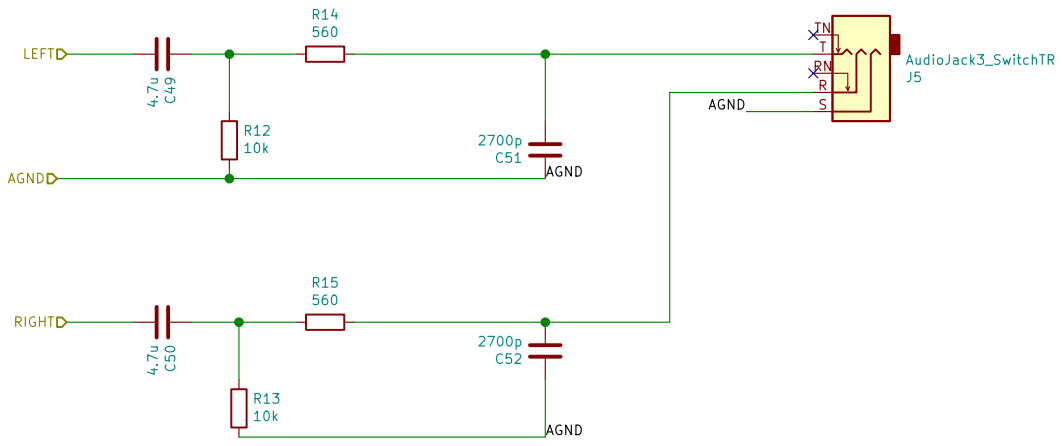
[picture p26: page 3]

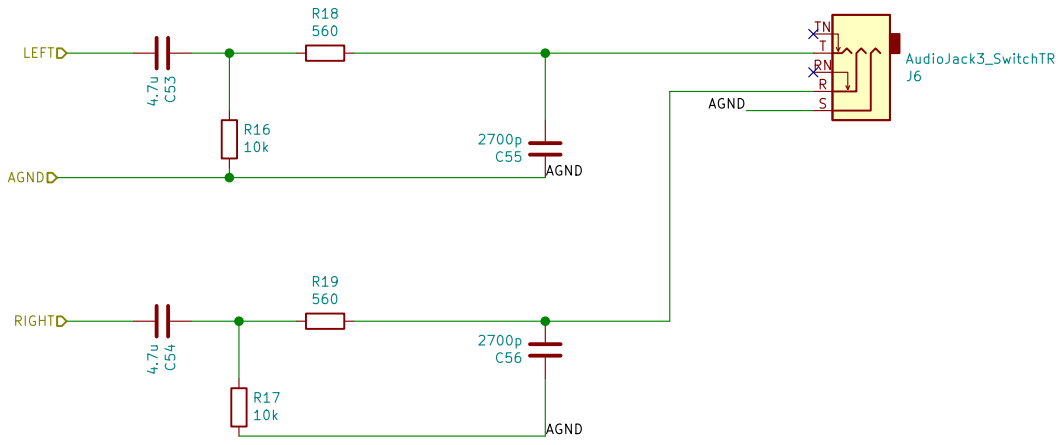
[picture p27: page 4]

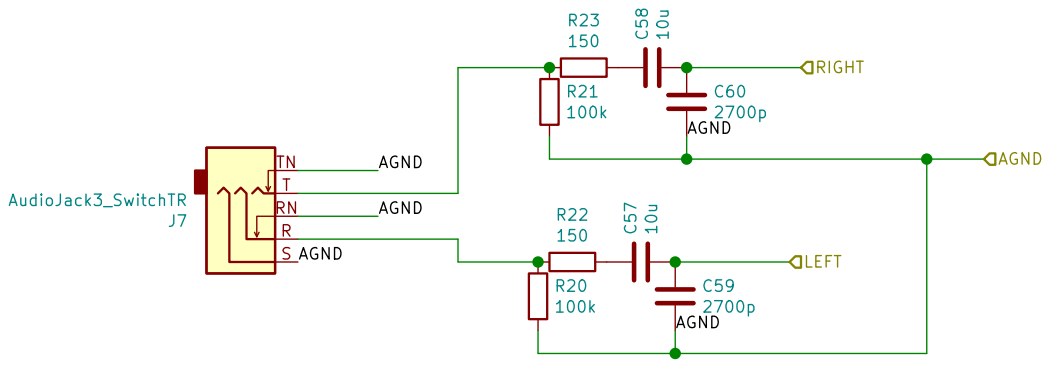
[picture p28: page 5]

Id: 5/8 Title: File: AudioIn.sch Sheet: /sheet5F6F72D7/ R22

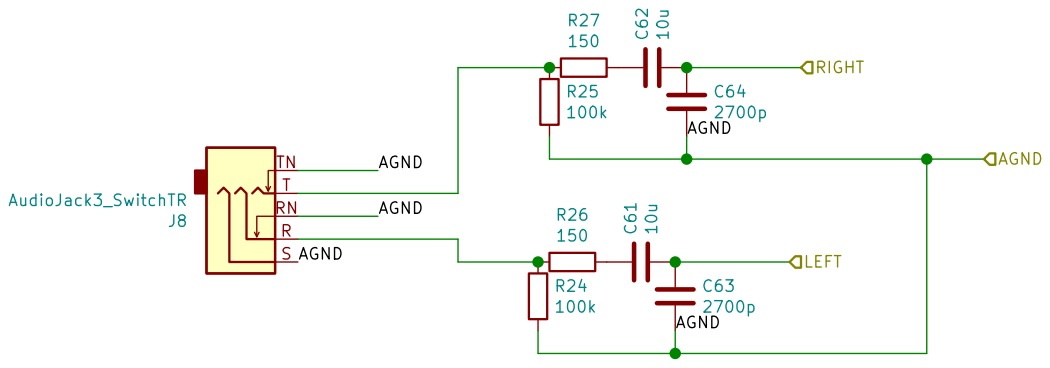
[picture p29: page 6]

Id: 6/8 Title: File: AudioIn.sch Sheet: /sheet5F6FD5A9/ R26

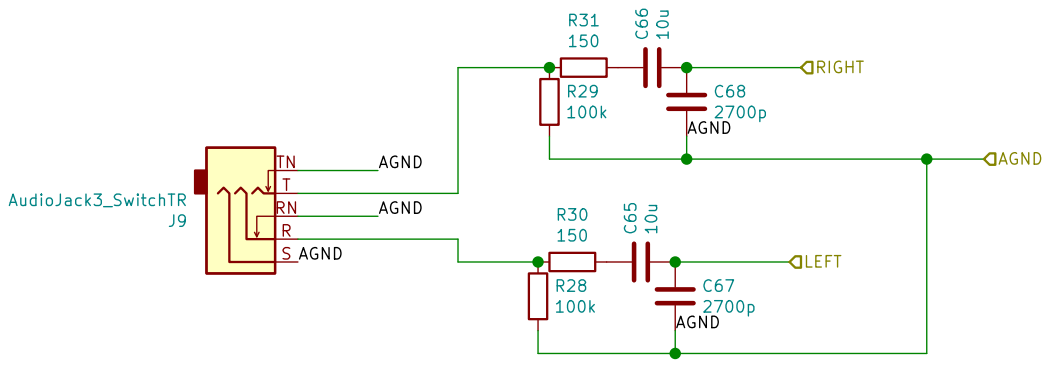
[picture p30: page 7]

Id: 7/8 Title: File: AudioIn.sch Sheet: /AudioIn/ R30

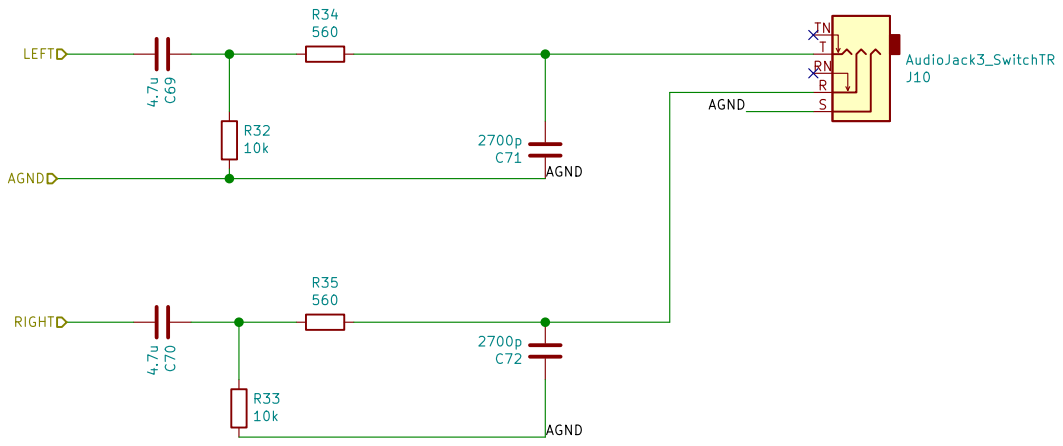
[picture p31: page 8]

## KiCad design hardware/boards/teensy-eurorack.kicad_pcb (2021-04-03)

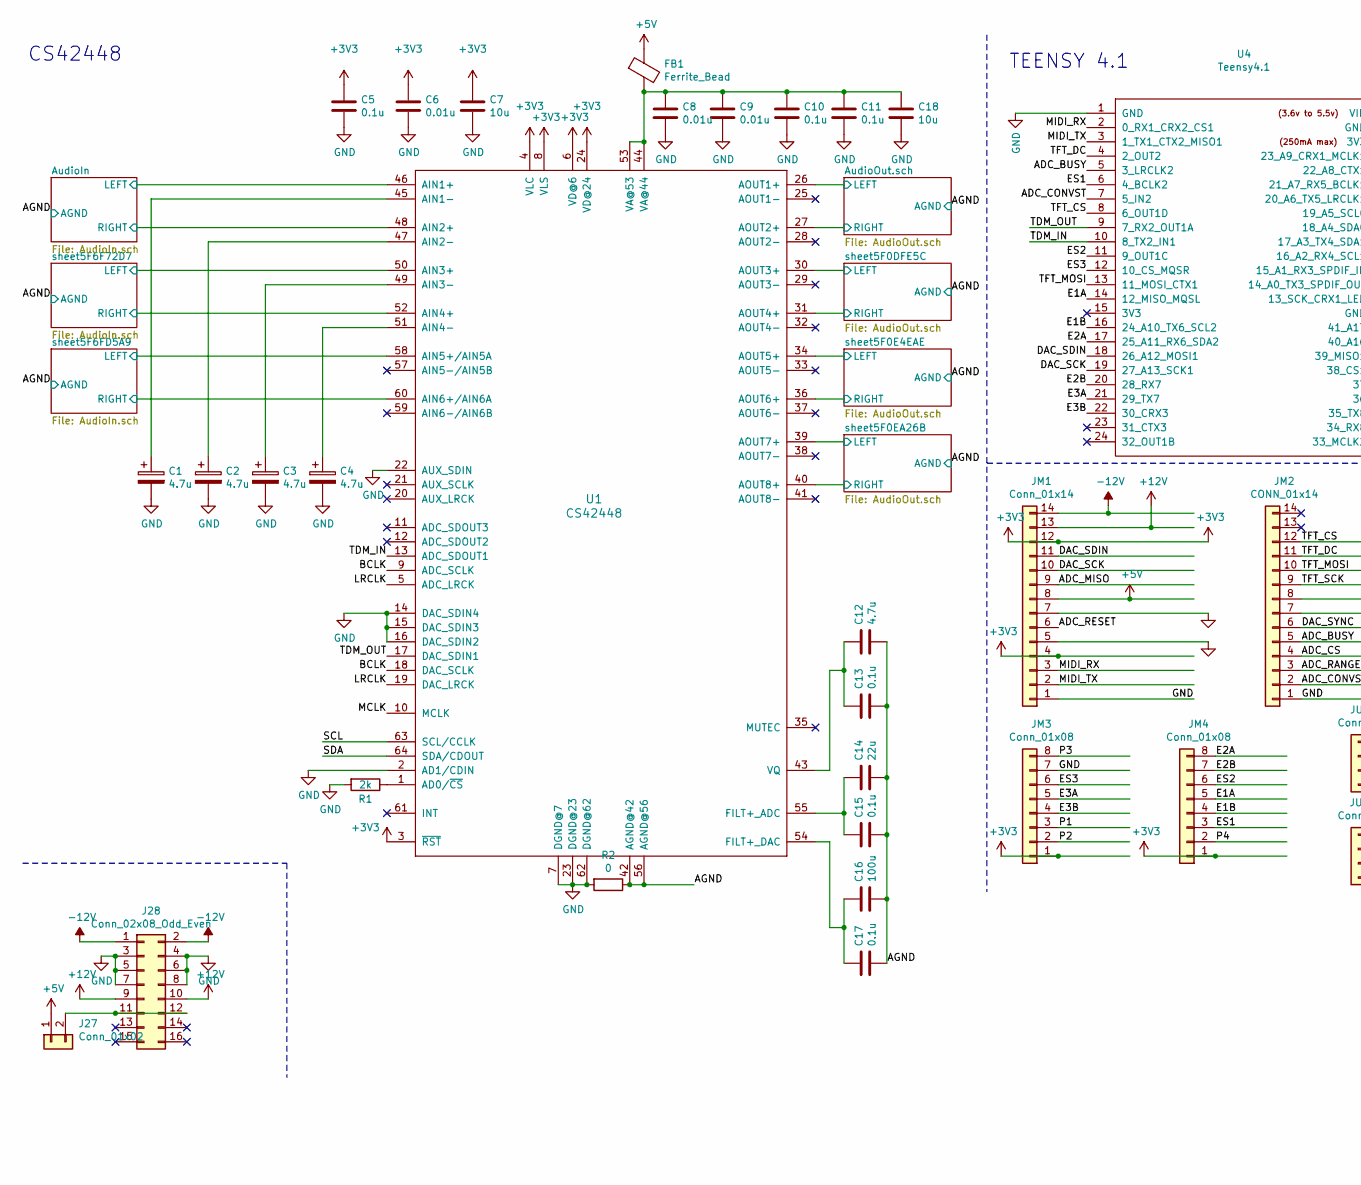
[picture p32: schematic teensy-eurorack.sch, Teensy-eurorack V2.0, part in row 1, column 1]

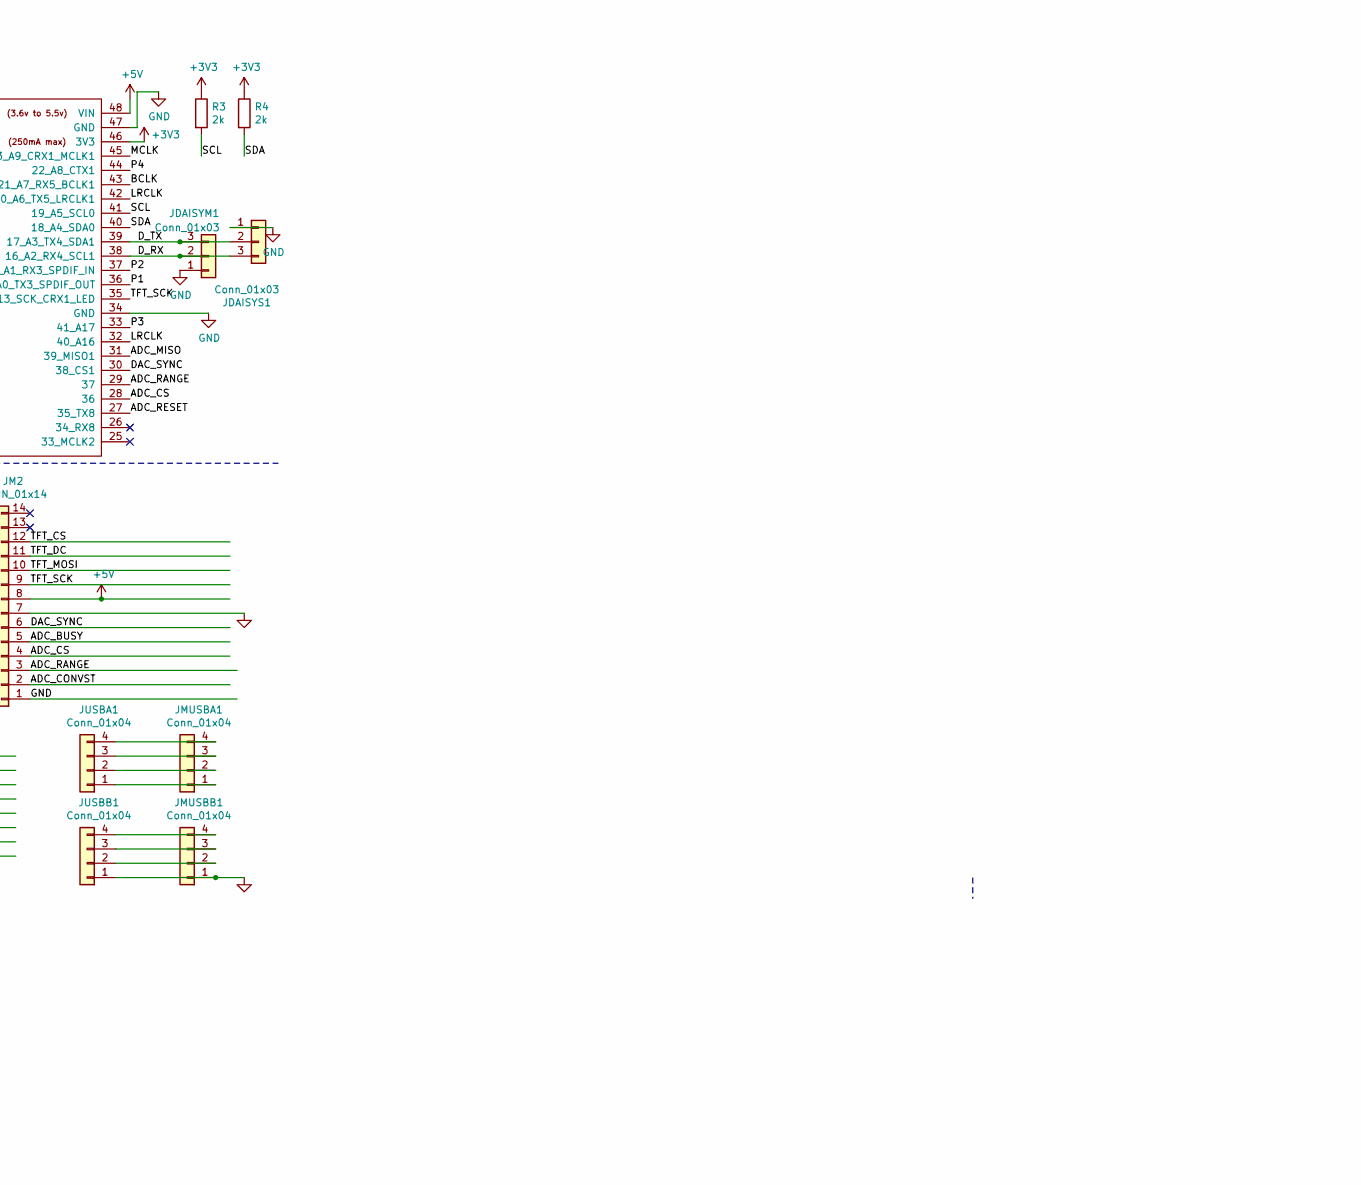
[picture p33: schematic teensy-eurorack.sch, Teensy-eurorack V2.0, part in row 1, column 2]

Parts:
C1, C2, C3, C4: 4.7u; CP_Radial_D5.0mm_P2.50mm
C5, C10, C11, C13, C15, C17: 0.1u; C_0805_2012Metric
C6, C8, C9: 0.01u; C_0805_2012Metric
C7, C18: 10u; C_0805_2012Metric
C12: 4.7u; C_0805_2012Metric
C14: 22u; C_0805_2012Metric
C16: 100u; C_1206_3216Metric
FB1: Ferrite_Bead; L_0603_1608Metric
J27: Conn_01x02; PinHeader_1x02_P2.54mm_Vertical
J28: Conn_02x08_Odd_Even; PinHeader_2x08_P2.54mm_Vertical
JDAISYM1: Conn_01x03; PinHeader_1x03_P2.54mm_Vertical
JDAISYS1: Conn_01x03; PinHeader_1x03_P2.54mm_Vertical
JM1: Conn_01x14; PinHeader_1x14_P2.54mm_Vertical
JM2: CONN_01x14; PinHeader_1x14_P2.54mm_Vertical
JM3, JM4: Conn_01x08; PinHeader_1x08_P2.54mm_Vertical
JMUSBA1: Conn_01x04; PinHeader_1x04_P2.54mm_Vertical
JMUSBB1: Conn_01x04; PinHeader_1x04_P2.54mm_Vertical
JUSBA1: Conn_01x04; PinHeader_1x04_P2.54mm_Vertical
JUSBB1: Conn_01x04; PinHeader_1x04_P2.54mm_Vertical
R1, R3, R4: 2k; R_0805_2012Metric
R2: 0; R_0805_2012Metric
U1: CS42448; LQFP-64_10x10mm_P0.5mm
U4: Teensy4.1; Teensy41_tht

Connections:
+3V3: C5.1, C6.1, C7.1, JM1.4, JM1.12, JM3.1, JM4.1, R3.1, R4.1, U1.3 (~RST~), U1.4 (VLC), U1.6 (VD@6), U1.8 (VLS), U1.24 (VD@24), U4.46 (3V3)
+5V: FB1.1, J27.1, JM1.8, JM2.8, U4.48 (VIN)
+12V: J28.9, J28.10, JM1.13
-12V: J28.1, J28.2, JM1.14
/ADC_BUSY: JM2.5, U4.5 (3_LRCLK2)
/ADC_CONVST: JM2.2, U4.7 (5_IN2)
/ADC_CS: JM2.4, U4.28 (36)
/ADC_MISO: JM1.9, U4.31 (39_MISO1)
/ADC_RANGE: JM2.3, U4.29 (37)
/ADC_RESET: JM1.6, U4.27 (35_TX8)
/AGND: C12.2, C13.2, C14.2, C15.2, C16.2, C17.2, R2.1, U1.42 (AGND@42), U1.56 (AGND@56); also elsewhere on the board
/AudioIn/LEFT: U1.46 (AIN1+); also elsewhere on the board
/AudioIn/RIGHT: U1.48 (AIN2+); also elsewhere on the board
/AudioOut.sch/LEFT: U1.26 (AOUT1+); also elsewhere on the board
/AudioOut.sch/RIGHT: U1.27 (AOUT2+); also elsewhere on the board
/BCLK: U1.9 (ADC_SCLK), U1.18 (DAC_SCLK), U4.43 (21_A7_RX5_BCLK1)
/DAC_SCK: JM1.10, U4.19 (27_A13_SCK1)
/DAC_SDIN: JM1.11, U4.18 (26_A12_MOSI1)
/DAC_SYNC: JM2.6, U4.30 (38_CS1)
/D_RX: JDAISYM1.2, JDAISYS1.3, U4.38 (16_A2_RX4_SCL1)
/D_TX: JDAISYM1.3, JDAISYS1.2, U4.39 (17_A3_TX4_SDA1)
/E1A: JM4.5, U4.14 (12_MISO_MQSL)
/E1B: JM4.4, U4.16 (24_A10_TX6_SCL2)
/E2A: JM4.8, U4.17 (25_A11_RX6_SDA2)
/E2B: JM4.7, U4.20 (28_RX7)
/E3A: JM3.5, U4.21 (29_TX7)
/E3B: JM3.4, U4.22 (30_CRX3)
/ES1: JM4.3, U4.6 (4_BCLK2)
/ES2: JM4.6, U4.11 (9_OUT1C)
/ES3: JM3.6, U4.12 (10_CS_MQSR)
/LRCLK: U1.5 (ADC_LRCK), U1.19 (DAC_LRCK), U4.32 (40_A16), U4.42 (20_A6_TX5_LRCLK1)
/MCLK: U1.10 (MCLK), U4.45 (23_A9_CRX1_MCLK1)
/MIDI_RX: JM1.3, U4.2 (0_RX1_CRX2_CS1)
/MIDI_TX: JM1.2, U4.3 (1_TX1_CTX2_MISO1)
/P1: JM3.3, U4.36 (14_A0_TX3_SPDIF_OUT)
/P2: JM3.2, U4.37 (15_A1_RX3_SPDIF_IN)
/P3: JM3.8, U4.33 (41_A17)
/P4: JM4.2, U4.44 (22_A8_CTX1)
/SCL: R3.2, U1.63 (SCL/CCLK), U4.41 (19_A5_SCL0)
/SDA: R4.2, U1.64 (SDA/CDOUT), U4.40 (18_A4_SDA0)
/TDM_IN: U1.13 (ADC_SDOUT1), U4.10 (8_TX2_IN1)
/TDM_OUT: U1.17 (DAC_SDIN1), U4.9 (7_RX2_OUT1A)
/TFT_CS: JM2.12, U4.8 (6_OUT1D)
/TFT_DC: JM2.11, U4.4 (2_OUT2)
/TFT_MOSI: JM2.10, U4.13 (11_MOSI_CTX1)
/TFT_SCK: JM2.9, U4.35 (13_SCK_CRX1_LED)
/sheet5F0DFE5C/LEFT: U1.30 (AOUT3+); also elsewhere on the board
/sheet5F0DFE5C/RIGHT: U1.31 (AOUT4+); also elsewhere on the board
/sheet5F0E4EAE/LEFT: U1.34 (AOUT5+); also elsewhere on the board
/sheet5F0E4EAE/RIGHT: U1.36 (AOUT6+); also elsewhere on the board
/sheet5F0EA26B/LEFT: U1.39 (AOUT7+); also elsewhere on the board
/sheet5F0EA26B/RIGHT: U1.40 (AOUT8+); also elsewhere on the board
/sheet5F6F72D7/LEFT: U1.50 (AIN3+); also elsewhere on the board
/sheet5F6F72D7/RIGHT: U1.52 (AIN4+); also elsewhere on the board
/sheet5F6FD5A9/LEFT: U1.58 (AIN5+/AIN5A); also elsewhere on the board
/sheet5F6FD5A9/RIGHT: U1.60 (AIN6+/AIN6A); also elsewhere on the board
GND: C1.2, C2.2, C3.2, C4.2, C5.2, C6.2, C7.2, C8.2, C9.2, C10.2, C11.2, C18.2, J28.3, J28.4, J28.5, J28.6, J28.7, J28.8, JDAISYM1.1, JDAISYS1.1, JM1.1, JM1.5, JM1.7, JM2.1, JM2.7, JM3.7, JMUSBB1.1, JUSBB1.1, R1.2, R2.2, U1.2 (AD1/CDIN), U1.7 (DGND@7), U1.14 (DAC_SDIN4), U1.15 (DAC_SDIN3), U1.16 (DAC_SDIN2), U1.22 (AUX_SDIN), U1.23 (DGND@23), U1.62 (DGND@62), U4.1 (GND), U4.34 (GND), U4.47 (GND)
unnamed: C1.1, U1.45 (AIN1-)
unnamed: C2.1, U1.47 (AIN2-)
unnamed: C3.1, U1.49 (AIN3-)
unnamed: C4.1, U1.51 (AIN4-)
unnamed: C8.1, C9.1, C10.1, C11.1, C18.1, FB1.2, U1.44 (VA@44), U1.53 (VA@53)
unnamed: C12.1, C13.1, U1.43 (VQ)
unnamed: C14.1, C15.1, U1.55 (FILT+_ADC)
unnamed: C16.1, C17.1, U1.54 (FILT+_DAC)
unnamed: J27.2, J28.11, J28.12
unnamed: JMUSBA1.1, JUSBA1.1
unnamed: JMUSBA1.2, JUSBA1.2
unnamed: JMUSBA1.3, JUSBA1.3
unnamed: JMUSBA1.4, JUSBA1.4
unnamed: JMUSBB1.2, JUSBB1.2
unnamed: JMUSBB1.3, JUSBB1.3
unnamed: JMUSBB1.4, JUSBB1.4
unnamed: R1.1, U1.1 (AD0/~CS~)

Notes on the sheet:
TEENSY 4.1
CS42448

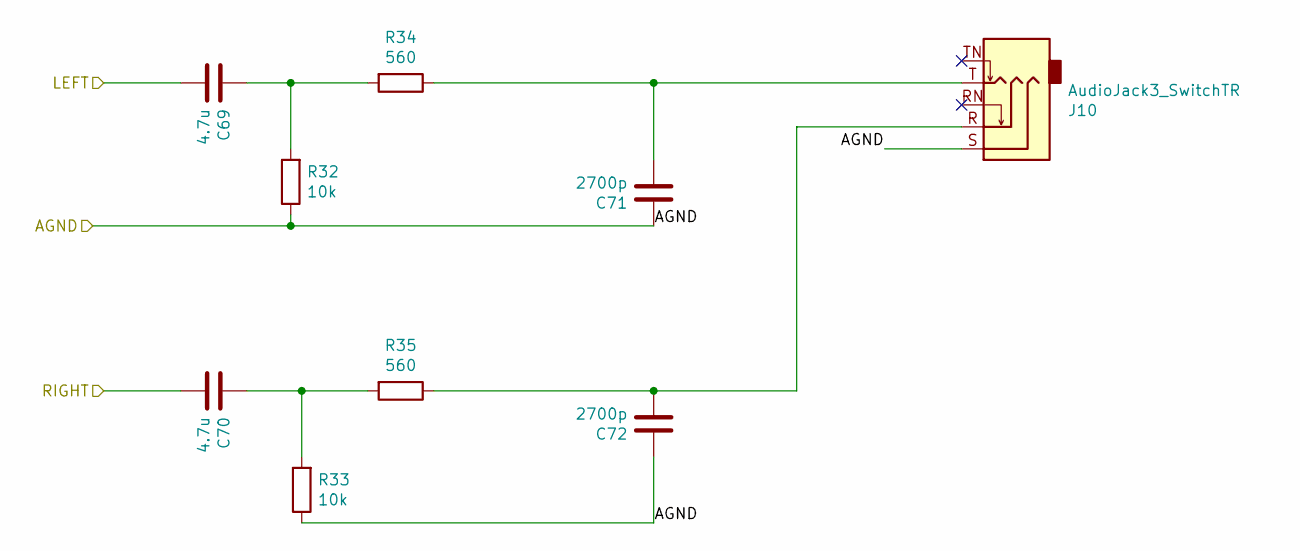
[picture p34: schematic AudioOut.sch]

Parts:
C45, C46: 4.7u; C_0805_2012Metric
C47, C48: 2700p; C_0805_2012Metric
J4: AudioJack3_SwitchTR; ACJS-MV5
R8, R9: 10k; R_0805_2012Metric
R10, R11: 560; R_0805_2012Metric

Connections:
/AGND: C47.1, C48.1, J4.S, R8.1, R9.1; also elsewhere on the board
/AudioOut.sch/LEFT: C45.2; also elsewhere on the board
/AudioOut.sch/RIGHT: C46.2; also elsewhere on the board
unnamed: C45.1, R8.2, R10.2
unnamed: C46.1, R9.2, R11.2
unnamed: C47.2, J4.T, R10.1
unnamed: C48.2, J4.R, R11.1

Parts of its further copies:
C49, C50, C53, C54, C69, C70: 4.7u; C_0805_2012Metric
C51, C52, C55, C56, C71, C72: 2700p; C_0805_2012Metric
J5, J6, J10: AudioJack3_SwitchTR; ACJS-MV5
R12, R13, R16, R17, R32, R33: 10k; R_0805_2012Metric
R14, R15, R18, R19, R34, R35: 560; R_0805_2012Metric

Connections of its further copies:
/AGND: C51.1, C52.1, C55.1, C56.1, C71.1, C72.1, J5.S, J6.S, J10.S, R12.1, R13.1, R16.1, R17.1, R32.1, R33.1; also elsewhere on the board
/sheet5F0DFE5C/LEFT: C49.2; also elsewhere on the board
/sheet5F0DFE5C/RIGHT: C50.2; also elsewhere on the board
/sheet5F0E4EAE/LEFT: C69.2; also elsewhere on the board
/sheet5F0E4EAE/RIGHT: C70.2; also elsewhere on the board
/sheet5F0EA26B/LEFT: C53.2; also elsewhere on the board
/sheet5F0EA26B/RIGHT: C54.2; also elsewhere on the board
unnamed: C49.1, R12.2, R14.2
unnamed: C50.1, R13.2, R15.2
unnamed: C51.2, J5.T, R14.1
unnamed: C52.2, J5.R, R15.1
unnamed: C53.1, R16.2, R18.2
unnamed: C54.1, R17.2, R19.2
unnamed: C55.2, J6.T, R18.1
unnamed: C56.2, J6.R, R19.1
unnamed: C69.1, R32.2, R34.2
unnamed: C70.1, R33.2, R35.2
unnamed: C71.2, J10.T, R34.1
unnamed: C72.2, J10.R, R35.1

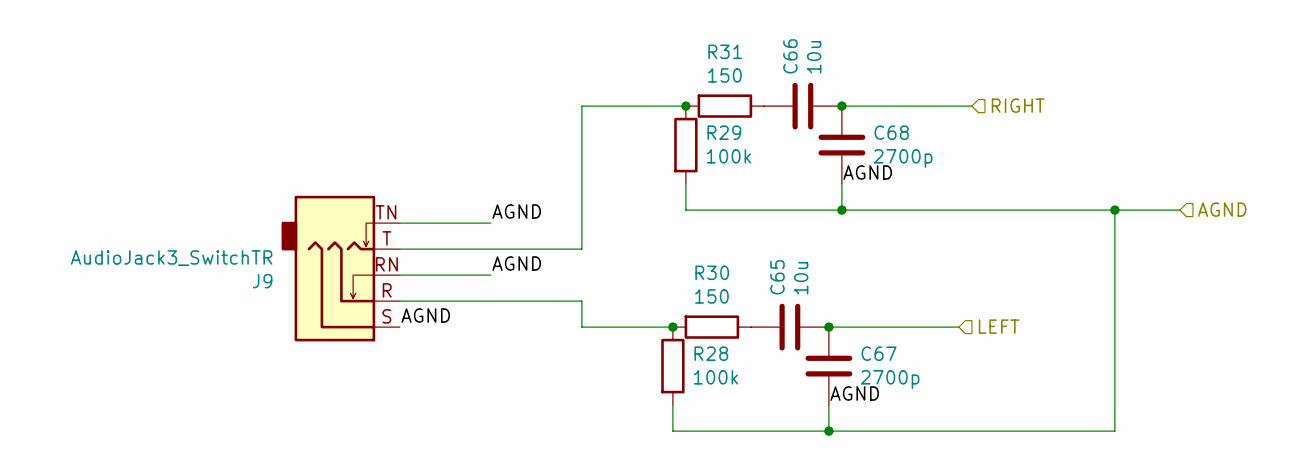
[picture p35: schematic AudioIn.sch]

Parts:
C65, C66: 10u; C_0805_2012Metric
C67, C68: 2700p; C_0805_2012Metric
J9: AudioJack3_SwitchTR; ACJS-MV5
R28, R29: 100k; R_0805_2012Metric
R30, R31: 150; R_0805_2012Metric

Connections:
/AGND: C67.2, C68.2, J9.RN, J9.S, J9.TN, R28.2, R29.2; also elsewhere on the board
/AudioIn/LEFT: C65.2, C67.1; also elsewhere on the board
/AudioIn/RIGHT: C66.2, C68.1; also elsewhere on the board
unnamed: C65.1, R30.1
unnamed: C66.1, R31.1
unnamed: J9.R, R28.1, R30.2
unnamed: J9.T, R29.1, R31.2

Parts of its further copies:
C57, C58, C61, C62: 10u; C_0805_2012Metric
C59, C60, C63, C64: 2700p; C_0805_2012Metric
J7, J8: AudioJack3_SwitchTR; ACJS-MV5
R20, R21, R24, R25: 100k; R_0805_2012Metric
R22, R23, R26, R27: 150; R_0805_2012Metric

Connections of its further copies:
/AGND: C59.2, C60.2, C63.2, C64.2, J7.RN, J7.S, J7.TN, J8.RN, J8.S, J8.TN, R20.2, R21.2, R24.2, R25.2; also elsewhere on the board
/sheet5F6F72D7/LEFT: C57.2, C59.1; also elsewhere on the board
/sheet5F6F72D7/RIGHT: C58.2, C60.1; also elsewhere on the board
/sheet5F6FD5A9/LEFT: C61.2, C63.1; also elsewhere on the board
/sheet5F6FD5A9/RIGHT: C62.2, C64.1; also elsewhere on the board
unnamed: C57.1, R22.1
unnamed: C58.1, R23.1
unnamed: C61.1, R26.1
unnamed: C62.1, R27.1
unnamed: J7.R, R20.1, R22.2
unnamed: J7.T, R21.1, R23.2
unnamed: J8.R, R24.1, R26.2
unnamed: J8.T, R25.1, R27.2

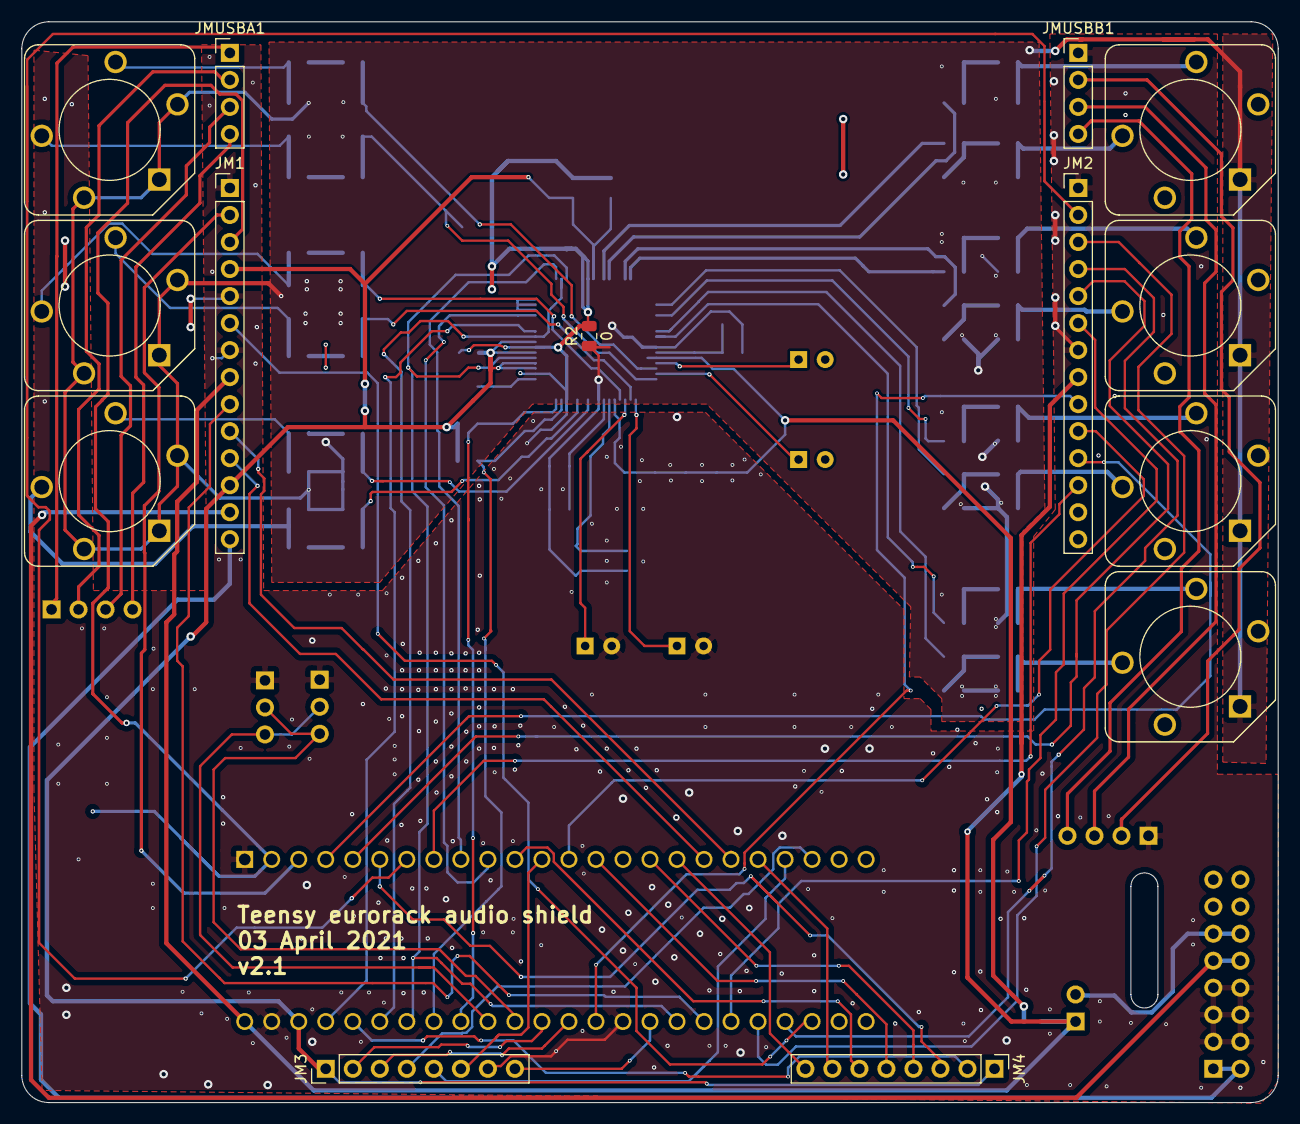
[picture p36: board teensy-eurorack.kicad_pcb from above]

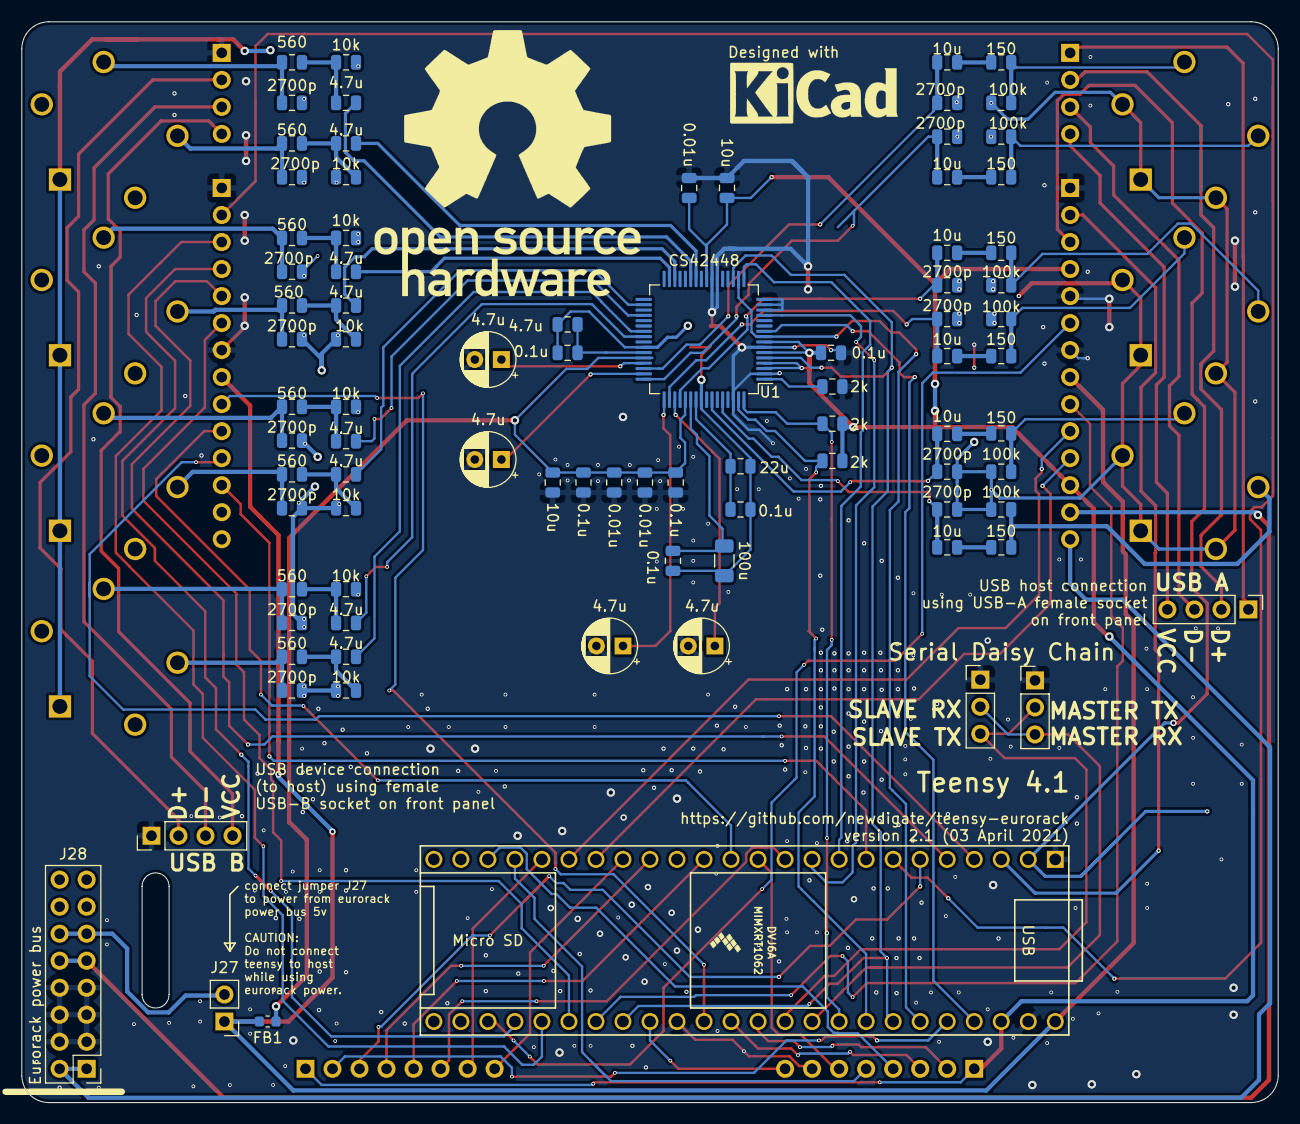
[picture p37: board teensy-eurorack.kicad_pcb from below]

Board: 2 copper layers, 118.1 x 101.6 mm, 100 parts (86 on the bottom side), 102 nets.

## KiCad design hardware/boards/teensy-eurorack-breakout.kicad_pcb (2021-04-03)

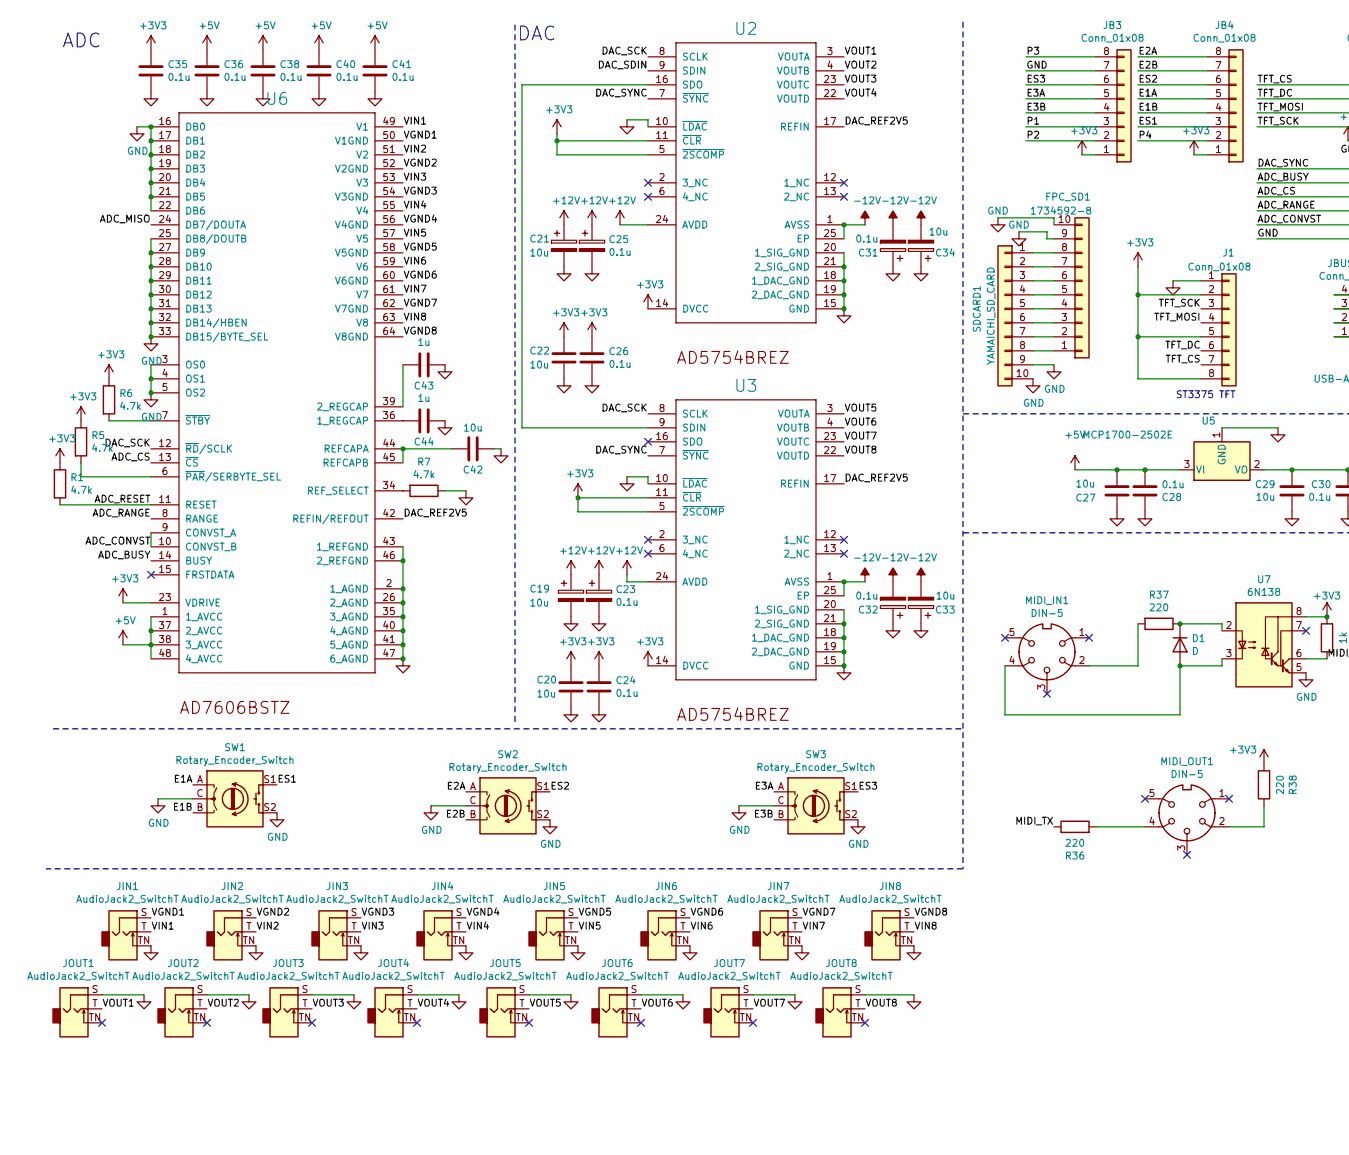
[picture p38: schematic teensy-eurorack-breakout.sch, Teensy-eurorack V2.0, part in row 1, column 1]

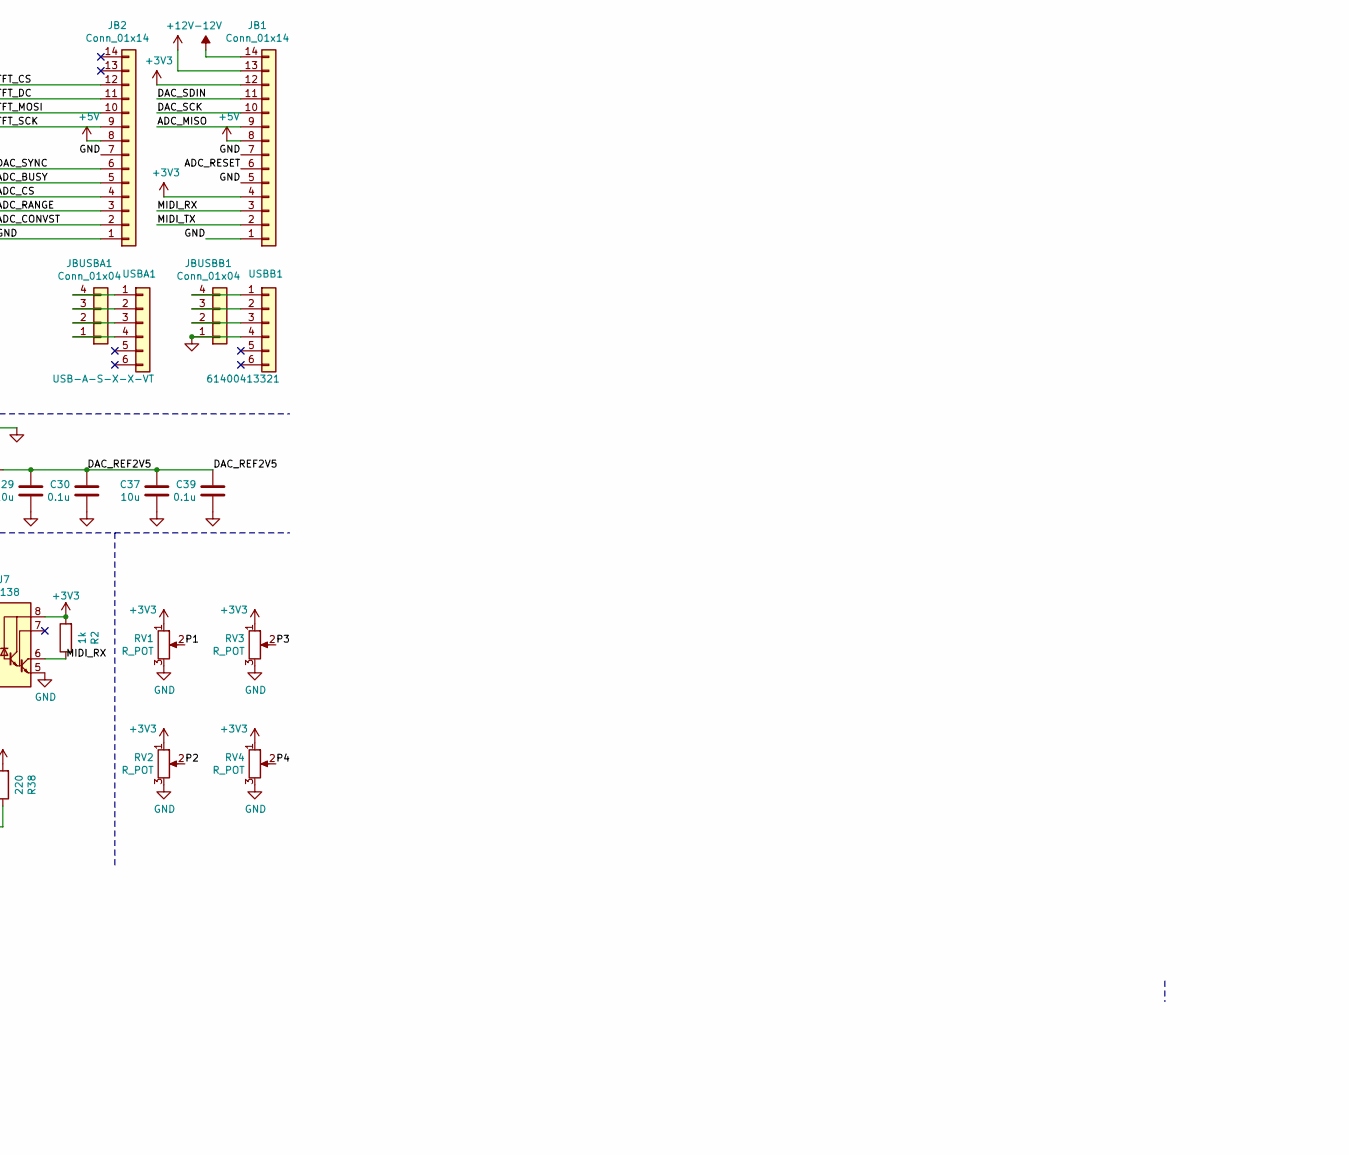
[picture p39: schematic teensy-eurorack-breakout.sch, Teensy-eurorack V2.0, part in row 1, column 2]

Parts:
C19, C21, C33, C34: 10u; CP_Radial_D5.0mm_P2.00mm
C20, C22, C27, C29, C37, C42: 10u; C_0805_2012Metric
C23, C25, C31, C32: 0.1u; CP_Radial_D5.0mm_P2.00mm
C24, C26, C28, C30, C35, C36, C38, C39, C40, C41: 0.1u; C_0805_2012Metric
C43, C44: 1u; C_0805_2012Metric
D1: D; D_0805_2012Metric
FPC_SD1: 1734592-8; HFW8R-1STE1LF
J1: Conn_01x08; ST7735
JB1, JB2: Conn_01x14; PinSocket_1x14_P2.54mm_Vertical
JB3, JB4: Conn_01x08; PinSocket_1x08_P2.54mm_Vertical
JBUSBA1: Conn_01x04; PinSocket_1x04_P2.54mm_Vertical
JBUSBB1: Conn_01x04; PinSocket_1x04_P2.54mm_Vertical
JIN1, JIN2, JIN3, JIN4, JIN5, JIN6, JIN7, JIN8: AudioJack2_SwitchT; WQP-PJ301M-12_JACK
JOUT1, JOUT2, JOUT3, JOUT4, JOUT5, JOUT6, JOUT7, JOUT8: AudioJack2_SwitchT; WQP-PJ301M-12_JACK
MIDI_IN1: DIN-5; OG-MIDI_SD-50BV
MIDI_OUT1: DIN-5; OG-MIDI_SD-50BV
R1, R5, R6, R7: 4.7k; R_0805_2012Metric
R2: 1k; R_0805_2012Metric
R36, R37, R38: 220; R_0805_2012Metric
RV1, RV2, RV3, RV4: R_POT; 9MM_SNAP-IN_POT
SDCARD1: YAMAICHI_SD_CARD; YAMAICHI_MICROSD_VERTICAL
SW1, SW2, SW3: Rotary_Encoder_Switch; RotaryEncoder_Alps_EC12E-Switch_Vertical_H20mm_CircularMoun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
U2, U3: AD5754BREZ; HTSSOP-24-1EP_4.4x7.8mm_P0.65mm_EP3.2x5mm
U5: MCP1700-2502E; SOT-23
U6: AD7606BSTZ; LQFP-64_10x10mm_P0.5mm
U7: 6N138; 6N138S
USBA1: USB-A-S-X-X-VT
USBB1: 61400413321; WURTH_ELECTRONICS_61400413321_0

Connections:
+3V3: C20.1, C22.1, C24.1, C26.1, C35.1, J1.2, J1.5, J1.8, JB1.4, JB1.12, JB3.1, JB4.1, R1.1, R2.2, R5.1, R6.1, R38.2, RV1.1, RV2.1, RV3.1, RV4.1, U2.5 (~2SCOMP~), U2.11 (~CLR~), U2.14 (DVCC), U3.5 (~2SCOMP~), U3.11 (~CLR~), U3.14 (DVCC), U6.23 (VDRIVE), U7.8 (VCC)
+5V: C27.2, C28.2, C36.1, C38.1, C40.1, C41.1, JB1.8, JB2.8, U5.3 (VI), U6.1 (1_AVCC), U6.37 (2_AVCC), U6.38 (3_AVCC), U6.48 (4_AVCC)
+12V: C19.1, C21.1, C23.1, C25.1, JB1.13, U2.24 (AVDD), U3.24 (AVDD)
-12V: C31.2, C32.2, C33.2, C34.2, JB1.14, U2.1 (AVSS), U2.25 (EP), U3.1 (AVSS), U3.25 (EP)
/ADC_BUSY: JB2.5, U6.14 (BUSY)
/ADC_CONVST: JB2.2, U6.9 (CONVST_A), U6.10 (CONVST_B)
/ADC_CS: JB2.4, U6.13 (~CS~)
/ADC_MISO: JB1.9, U6.24 (DB7/DOUTA)
/ADC_RANGE: JB2.3, U6.8 (RANGE)
/ADC_RESET: JB1.6, R1.2, U6.11 (RESET)
/DAC_REF2V5: C29.1, C30.1, C37.1, C39.1, U2.17 (REFIN), U3.17 (REFIN), U5.2 (VO), U6.42 (REFIN/REFOUT)
/DAC_SCK: JB1.10, U2.8 (SCLK), U3.8 (SCLK), U6.12 (~RD~/SCLK)
/DAC_SDIN: JB1.11, U2.9 (SDIN)
/DAC_SYNC: JB2.6, U2.7 (~SYNC~), U3.7 (~SYNC~)
/E1A: JB4.5, SW1.A
/E1B: JB4.4, SW1.B
/E2A: JB4.8, SW2.A
/E2B: JB4.7, SW2.B
/E3A: JB3.5, SW3.A
/E3B: JB3.4, SW3.B
/ES1: JB4.3, SW1.S1
/ES2: JB4.6, SW2.S1
/ES3: JB3.6, SW3.S1
/MIDI_RX: JB1.3, R2.1, U7.6 (VO2)
/MIDI_TX: JB1.2, R36.1
/P1: JB3.3, RV1.2
/P2: JB3.2, RV2.2
/P3: JB3.8, RV3.2
/P4: JB4.2, RV4.2
/TFT_CS: J1.7, JB2.12
/TFT_DC: J1.6, JB2.11
/TFT_MOSI: J1.4, JB2.10
/TFT_SCK: J1.3, JB2.9
/VGND1: JIN1.S, U6.50 (V1GND)
/VGND2: JIN2.S, U6.52 (V2GND)
/VGND3: JIN3.S, U6.54 (V3GND)
/VGND4: JIN4.S, U6.56 (V4GND)
/VGND5: JIN5.S, U6.58 (V5GND)
/VGND6: JIN6.S, U6.60 (V6GND)
/VGND7: JIN7.S, U6.62 (V7GND)
/VGND8: JIN8.S, U6.64 (V8GND)
/VIN1: JIN1.T, U6.49 (V1)
/VIN2: JIN2.T, U6.51 (V2)
/VIN3: JIN3.T, U6.53 (V3)
/VIN4: JIN4.T, U6.55 (V4)
/VIN5: JIN5.T, U6.57 (V5)
/VIN6: JIN6.T, U6.59 (V6)
/VIN7: JIN7.T, U6.61 (V7)
/VIN8: JIN8.T, U6.63 (V8)
/VOUT1: JOUT1.T, U2.3 (VOUTA)
/VOUT2: JOUT2.T, U2.4 (VOUTB)
/VOUT3: JOUT3.T, U2.23 (VOUTC)
/VOUT4: JOUT4.T, U2.22 (VOUTD)
/VOUT5: JOUT5.T, U3.3 (VOUTA)
/VOUT6: JOUT6.T, U3.4 (VOUTB)
/VOUT7: JOUT7.T, U3.23 (VOUTC)
/VOUT8: JOUT8.T, U3.22 (VOUTD)
GND: C19.2, C20.2, C21.2, C22.2, C23.2, C24.2, C25.2, C26.2, C27.1, C28.1, C29.2, C30.2, C31.1, C32.1, C33.1, C34.1, C35.2, C36.2, C37.2, C38.2, C39.2, C40.2, C41.2, C42.1, C43.1, C44.1, FPC_SD1.9, FPC_SD1.10, J1.1, JB1.1, JB1.5, JB1.7, JB2.1, JB2.7, JB3.7, JBUSBB1.1, JIN1.TN, JIN2.TN, JIN3.TN, JIN4.TN, JIN5.TN, JIN6.TN, JIN7.TN, JIN8.TN, JOUT1.S, JOUT2.S, JOUT3.S, JOUT4.S, JOUT5.S, JOUT6.S, JOUT7.S, JOUT8.S, R7.1, RV1.3, RV2.3, RV3.3, RV4.3, SDCARD1.9, SDCARD1.10, SW1.C, SW1.S2, SW2.C, SW2.S2, SW3.C, SW3.S2, U2.10 (~LDAC~), U2.15 (GND), U2.18 (1_DAC_GND), U2.19 (2_DAC_GND), U2.20 (1_SIG_GND), U2.21 (2_SIG_GND), U3.10 (~LDAC~), U3.15 (GND), U3.18 (1_DAC_GND), U3.19 (2_DAC_GND), U3.20 (1_SIG_GND), U3.21 (2_SIG_GND), U5.1 (GND), U6.2 (1_AGND), U6.3 (OS0), U6.4 (OS1), U6.5 (OS2), U6.16 (DB0), U6.17 (DB1), U6.18 (DB2), U6.19 (DB3), U6.20 (DB4), U6.21 (DB5), U6.22 (DB6), U6.25 (DB8/DOUTB), U6.26 (2_AGND), U6.27 (DB9), U6.28 (DB10), U6.29 (DB11), U6.30 (DB12), U6.31 (DB13), U6.32 (DB14/HBEN), U6.33 (DB15/BYTE_SEL), U6.35 (3_AGND), U6.40 (4_AGND), U6.41 (5_AGND), U6.43 (1_REFGND), U6.46 (2_REFGND), U6.47 (6_AGND), U7.5 (GND), USBB1.4
unnamed: C42.2, U6.44 (REFCAPA), U6.45 (REFCAPB)
unnamed: C43.2, U6.39 (2_REGCAP)
unnamed: C44.2, U6.36 (1_REGCAP)
unnamed: D1.1 (K), R37.1, U7.2 (C1)
unnamed: D1.2 (A), MIDI_IN1.4, U7.3 (C2)
unnamed: FPC_SD1.1, SDCARD1.8
unnamed: FPC_SD1.2, SDCARD1.7
unnamed: FPC_SD1.3, SDCARD1.6
unnamed: FPC_SD1.4, SDCARD1.5
unnamed: FPC_SD1.5, SDCARD1.4
unnamed: FPC_SD1.6, SDCARD1.3
unnamed: FPC_SD1.7, SDCARD1.2
unnamed: FPC_SD1.8, SDCARD1.1
unnamed: JBUSBA1.1, USBA1.4
unnamed: JBUSBA1.2, USBA1.3
unnamed: JBUSBA1.3, USBA1.2
unnamed: JBUSBA1.4, USBA1.1
unnamed: JBUSBB1.2, USBB1.3
unnamed: JBUSBB1.3, USBB1.2
unnamed: JBUSBB1.4, USBB1.1
unnamed: MIDI_IN1.2, R37.2
unnamed: MIDI_OUT1.2, R38.1
unnamed: MIDI_OUT1.4, R36.2
unnamed: R5.2, U6.6 (~PAR~/SERBYTE_SEL)
unnamed: R6.2, U6.7 (~STBY~)
unnamed: R7.2, U6.34 (REF_SELECT)
unnamed: U2.16 (SDO), U3.9 (SDIN)

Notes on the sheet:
ADC
ST3375 TFT
DAC

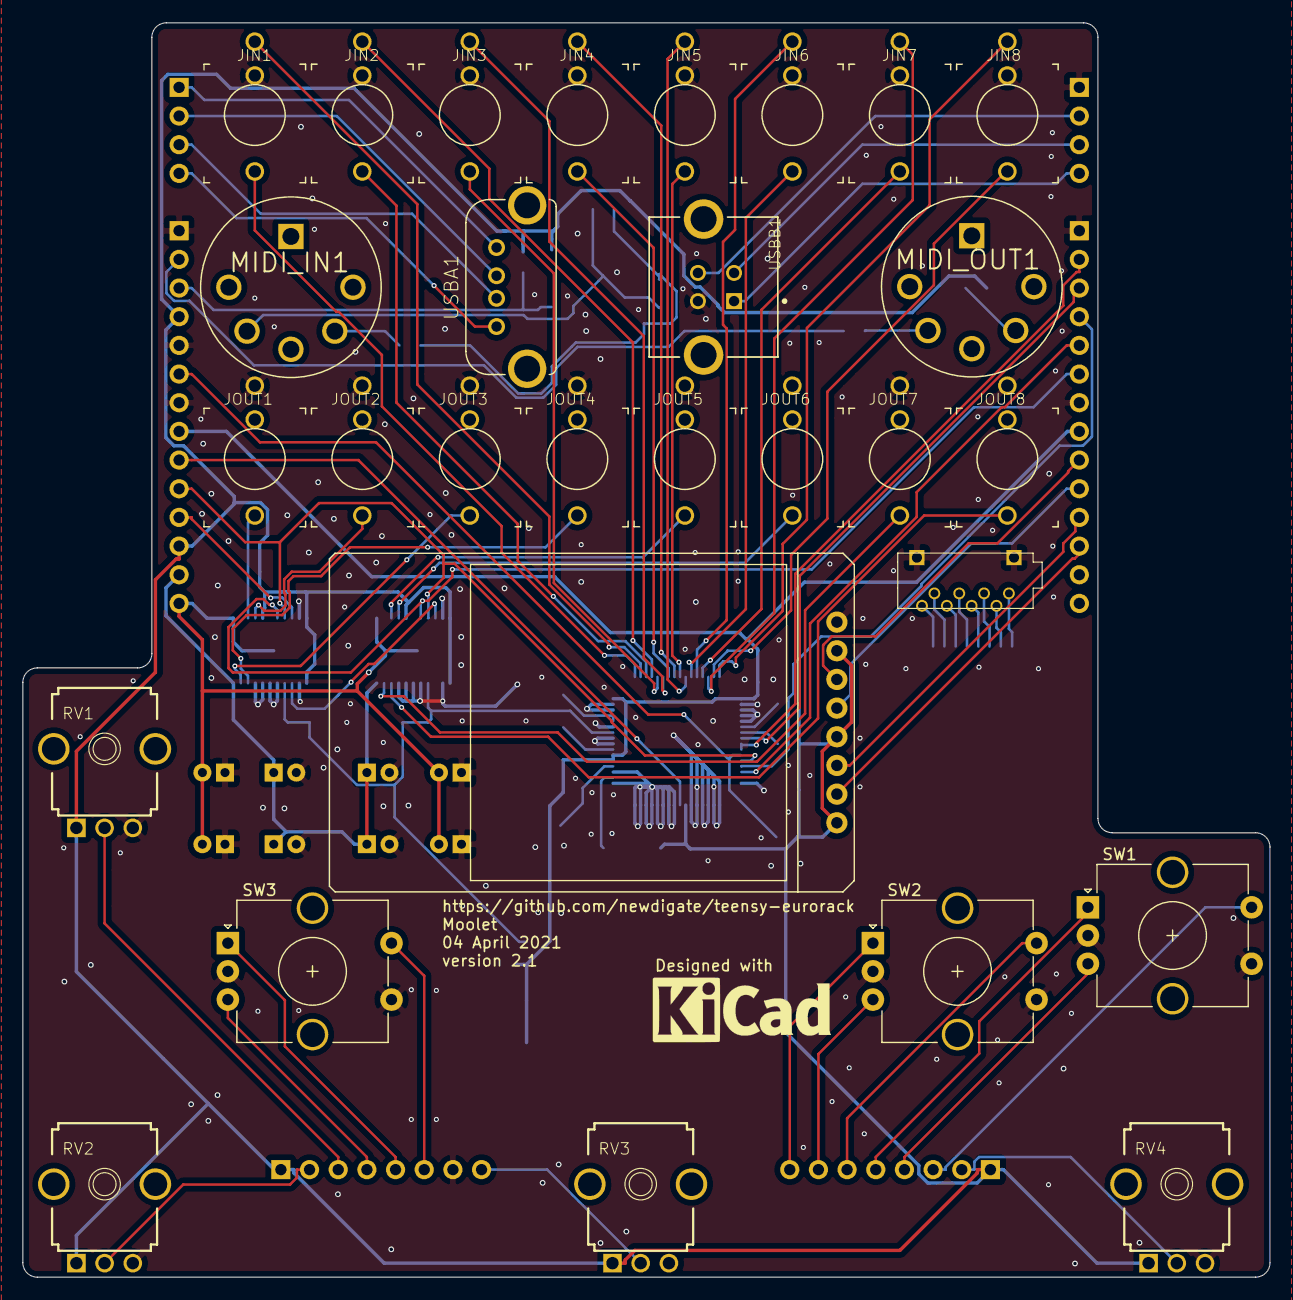
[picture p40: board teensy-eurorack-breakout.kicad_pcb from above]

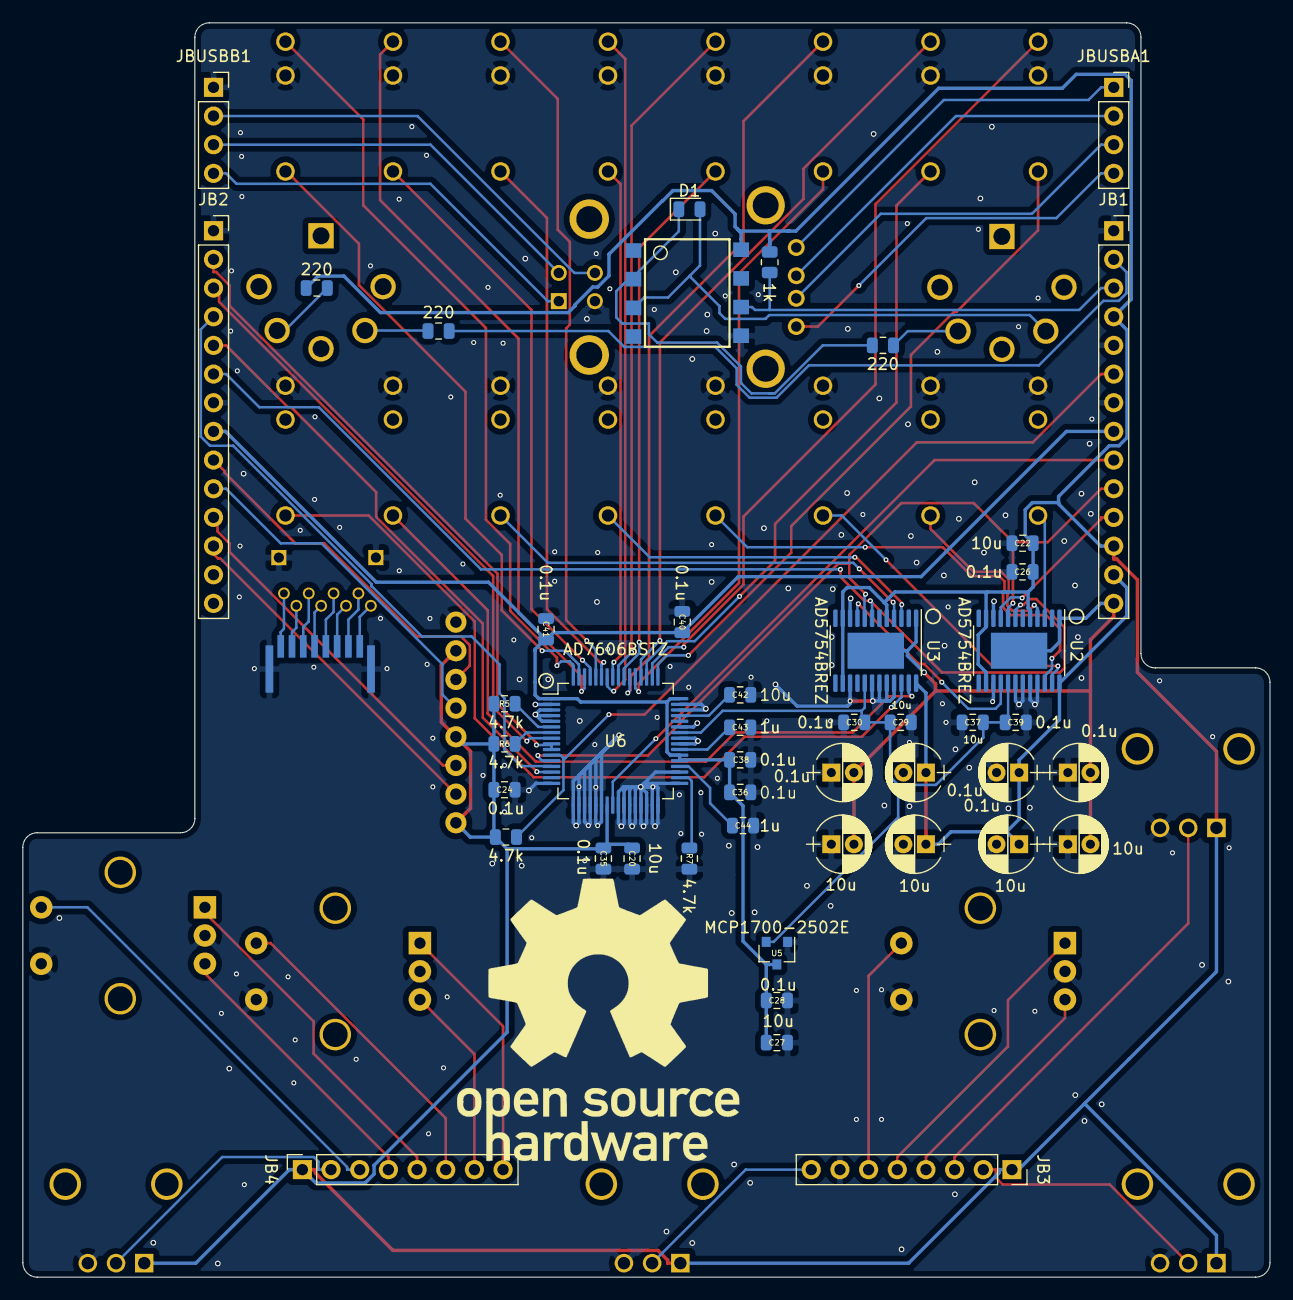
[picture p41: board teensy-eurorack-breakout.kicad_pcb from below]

Board: 2 copper layers, 110.5 x 111.1 mm, 76 parts (47 on the bottom side), 85 nets.

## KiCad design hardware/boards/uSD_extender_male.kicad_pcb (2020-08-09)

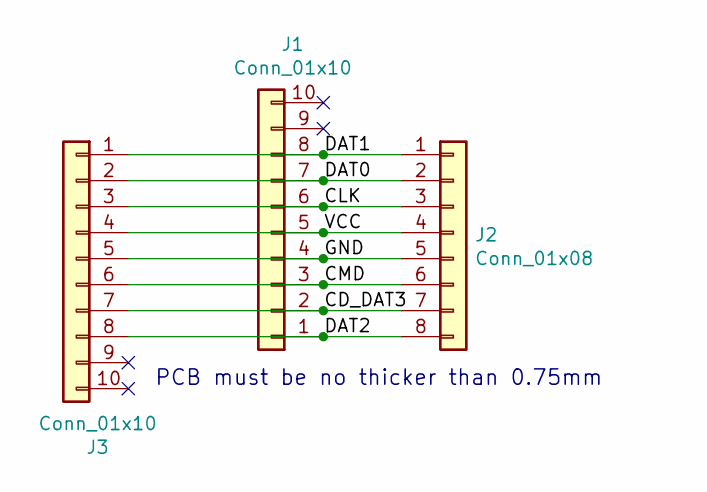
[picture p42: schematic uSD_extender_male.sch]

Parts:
J1, J3: Conn_01x10; HFW8R-1STE1LF
J2: Conn_01x08; MICRO-SDCARD

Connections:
/CD_DAT3: J1.2, J2.7, J3.7
/CLK: J1.6, J2.3, J3.3
/CMD: J1.3, J2.6, J3.6
/DAT0: J1.7, J2.2, J3.2
/DAT1: J1.8, J2.1, J3.1
/DAT2: J1.1, J2.8, J3.8
/GND: J1.4, J2.5, J3.5
/VCC: J1.5, J2.4, J3.4

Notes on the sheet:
PCB must be no thicker than 0.75mm

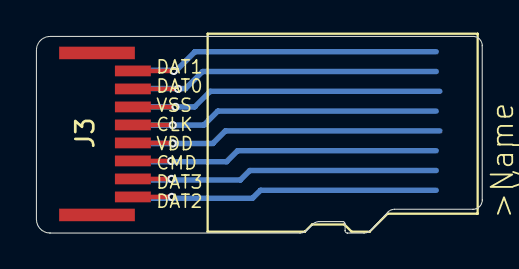
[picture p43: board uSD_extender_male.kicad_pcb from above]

Board: 2 copper layers, 24.8 x 10.9 mm, 3 parts (0 on the bottom side), 8 nets.

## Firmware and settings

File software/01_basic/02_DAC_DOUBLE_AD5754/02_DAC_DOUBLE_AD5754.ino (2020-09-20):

#include <SPI.h> //MUST include the SPI library or this won't work.

/* AD5754R Register Map */
#define AD5754R_REG_DAC             0x00 // DAC register
#define AD5754R_REG_RANGE_SELECT    0x01 // Output range select register
#define AD5754R_REG_POWER_CONTROL   0x02 // Power control register
#define AD5754R_REG_CONTROL         0x03 // Control register

/* AD5754R Channel Address */
#define AD5754R_DAC_A               0x00 // Address of channel A 
#define AD5754R_DAC_B               0x01 // Address of channel B
#define AD5754R_DAC_C               0x02 // Address of channel C
#define AD5754R_DAC_D               0x03 // Address of channel D
#define AD5754R_DAC_ALL             0x04 // All four DACs 

/* AD5754R Range Bits */
#define AD5754R_UNIPOLAR_5_RANGE    0x00 // 0..+5(V)        
#define AD5754R_UNIPOLAR_10_RANGE   0x01 // 0..+10(V)       
#define AD5754R_UNIPOLAR_10_8_RANGE 0x02 // 0..+10.8(V)     
#define AD5754R_BIPOLAR_5_RANGE     0x03 // -5..+5(V)       
#define AD5754R_BIPOLAR_10_RANGE    0x04 // -10...+10(V)    
#define AD5754R_BIPOLAR_10_8_RANGE  0x05 // -10.8...+10.8(V) 

/* Control Functions */
#define AD5754R_NOP_OPERATION       0x00 // No operation instruction used in readback operations.
#define AD5754R_SDO_DISABLE         0x11 // Set by the user to disable the SDO output.
#define AD5754R_CLR_SELECT          0x12 // Selects the clear code: 0V, Midscale or Negative full scale.
#define AD5754R_CLAMP_ENABLE        0x14 // Set by the user to enable the current-limit clamp.
#define AD5754R_TSD_ENABLE          0x18 // Set by the user to enable the thermal shutdown feature.
#define AD5754R_CLEAR               0x40 // Sets the DAC registers to the clear code and updates the outputs.
#define AD5754R_LOAD                0x50 // Updates the DAC registers and, consequently, the DAC outputs.

#define DA_SYNC 16
#define DA_CLK 27
#define DA_MOSI 26
#define DA_MISO 41
#define TFT_CS 6

void setup() {
  // put your setup code here, to run once:
  pinMode(DA_SYNC, OUTPUT);
  digitalWrite(DA_SYNC, HIGH); 

  pinMode(TFT_CS, OUTPUT);
  digitalWrite(TFT_CS, HIGH); 

  Serial.begin(9600);
  /*
    while (!Serial) {
    delay(100);
  }
  */

  Serial.println("connected...");
   
  SPI1.setSCK  (DA_CLK);
  SPI1.setMOSI (DA_MOSI);
  SPI1.setMISO (DA_MISO);
  SPI1.begin();
  
  delay(10);

  AD5754R_SetRegisterValue(AD5754R_REG_POWER_CONTROL,0x00,0x0f);

  //AD5754R_SetPower(AD5754R_DAC_ALL, 1);
  
  AD5754R_ControlFunction(AD5754R_SDO_DISABLE, 1);
   
  AD5754R_RangeSelect(AD5754R_DAC_ALL, AD5754R_UNIPOLAR_5_RANGE);
 
  AD5754R_LoadDac2(AD5754R_DAC_ALL, 0xffff, AD5754R_DAC_ALL, 0xffff);

//  AD5754R_GetRegisterValue(AD5754R_REG_POWER_CONTROL);
}


uint16_t control_voltage1 = 0x0000;
uint16_t control_voltage2 = 0x0000;

void loop() {
  control_voltage1++;
  control_voltage2--;
  AD5754R_LoadDac2(AD5754R_DAC_A, control_voltage1, AD5754R_DAC_A, control_voltage2);
  AD5754R_LoadDac2(AD5754R_DAC_B, control_voltage1, AD5754R_DAC_B, control_voltage2);
  AD5754R_LoadDac2(AD5754R_DAC_C, control_voltage1, AD5754R_DAC_C, control_voltage2);
  AD5754R_LoadDac2(AD5754R_DAC_D, control_voltage1, AD5754R_DAC_D, control_voltage2);
  delayMicroseconds(1);
}

void SendData(unsigned char *p){ //CHECKED OK
  //Serial.print("(send: ");

  digitalWrite(DA_SYNC,LOW);
  for (int i=2; i>= 0; i--){ //MSB first

    SPI1.transfer (p[i]);
    //Serial.print(p[i], BIN);
    //Serial.print(" ");
  }
  digitalWrite(DA_SYNC,HIGH);
  //Serial.println(")");
} 

void SendData2(unsigned char *p){ //CHECKED OK
  //Serial.print("(send: ");

  digitalWrite(DA_SYNC,LOW);
  for (int i=5; i>= 0; i--){ //MSB first

    SPI1.transfer (p[i]);
    //Serial.print(p[i], BIN);
    //Serial.print(" ");
  }
  digitalWrite(DA_SYNC,HIGH);
  //Serial.println(")");
} 

void SPIReadData(byte raw[]){
  digitalWrite(DA_SYNC, LOW);
  Serial.printf("SPIReadData: ");

  //Send  0001 8000 0000 0000 0000 0000 = NOP
  //Read 3 bytes

  for (int i=2; i>= 0; i--){

      raw[i] = SPI1.transfer(0x180000);
      Serial.printf("%x, ", raw[i]);

  }
  
  Serial.printf("\n");
  digitalWrite(DA_SYNC, HIGH); 
}

void AD5754R_SetRegisterValue2(unsigned char regBits,
                             unsigned char adrBits,
                             unsigned short registerValue,
                             unsigned char regBits2,
                             unsigned char adrBits2,
                             unsigned short registerValue2)
{
   
    unsigned char registerWord[6] = {0};
    registerWord[2] = (regBits << 3) + adrBits;
    registerWord[1] = (registerValue & 0xFF00) >> 8;
    registerWord[0] = (registerValue & 0x00FF) >> 0;

    registerWord[5] = (regBits2 << 3) + adrBits2;
    registerWord[4] = (registerValue2 & 0xFF00) >> 8;
    registerWord[3] = (registerValue2 & 0x00FF) >> 0;
    SendData2(registerWord);
}

void AD5754R_SetRegisterValue(unsigned char regBits,
                             unsigned char adrBits,
                             unsigned short registerValue)
{
   
    unsigned char registerWord[3] = {0};
    registerWord[2] = (regBits << 3) + adrBits;
    registerWord[1] = (registerValue & 0xFF00) >> 8;
    registerWord[0] = (registerValue & 0x00FF) >> 0;
    SendData(registerWord);
}


unsigned short AD5754R_GetRegisterValue(unsigned char regBits,
                                       unsigned char adrBits)
{
    unsigned char registerWord[3]   = {0};
    unsigned short data             = 0;
    registerWord[2] = (1 << 7) + (regBits << 3) + adrBits;
    registerWord[1] = 0;
    registerWord[0] = 0;
    SendData(registerWord);
    
    registerWord[2] = 0x18; // NOP instruction used in readback operations.
    registerWord[1] = 0;
    registerWord[0] = 0;
    SPIReadData(registerWord);
    data = (registerWord[1] << 8) + registerWord[2];
    Serial.printf("AD5754R_GetRegisterValue returns %x (BIN:",data);
    Serial.print(data, BIN);
    Serial.println();

    return(data);
}

/***************************************************************************//**
 * @brief Enables/disables indicated DAC channels.
 *
 * @param dacChannel - DAC channel or channels to be enabled/disabled.
 *                     Example: AD5754R_DAC_A - Channel A.
 *                              AD5754R_DAC_B - Channel B.
 *                              AD5754R_DAC_C - Channel C.
 *                              AD5754R_DAC_D - Channel D.
 *                              AD5754R_DAC_ALL - Channel ALL.
 * @param onOff - Enable or disable channel.
 *                Example: 0x0 - Off.
                                                                              *                         0x1 - On.
                                                                              *
                                                                              * @return None.
                                                                              *******************************************************************************/
void AD5754R_SetPower(unsigned char dacChannel, unsigned char onOff)
{
    Serial.printf("AD5754R_SetPower(%x, %x)...", dacChannel, onOff );
    unsigned short oldPowerCtl = 0;
    unsigned short newPowerCtl = 0;
    if(dacChannel == AD5754R_DAC_ALL)
    {
        dacChannel = 0x0F;
    }
    else
    {
        dacChannel = (1 << dacChannel);
    }
    oldPowerCtl = AD5754R_GetRegisterValue(AD5754R_REG_POWER_CONTROL,0x00);
    newPowerCtl = oldPowerCtl & ~dacChannel;
    newPowerCtl = newPowerCtl | (onOff * dacChannel);
    AD5754R_SetRegisterValue(AD5754R_REG_POWER_CONTROL,0x00,newPowerCtl);
}

/***************************************************************************//**
 * @brief Writes data into a DAC channel register.
 *
 * @param dacChannel - DAC channel or channels to be written.
 * @param dacValue - Value written in DAC register.
 *
 * @return None.
*******************************************************************************/
void AD5754R_LoadDac(unsigned char dacChannel, unsigned short dacValue)
{
    //Serial.printf("AD5754R_LoadDac(%x, %x)...", dacChannel, dacValue );
    AD5754R_SetRegisterValue(AD5754R_REG_DAC, dacChannel, dacValue);
}

void AD5754R_LoadDac2(unsigned char dacChannel, unsigned short dacValue, unsigned char dac2Channel, unsigned short dac2Value)
{
    //Serial.printf("AD5754R_LoadDac(%x, %x)...", dacChannel, dacValue );
    AD5754R_SetRegisterValue2(AD5754R_REG_DAC, dacChannel, dacValue, AD5754R_REG_DAC, dac2Channel, dac2Value);
}

/***************************************************************************//**
 * @brief Selects the output range of a DAC channel.
 *
 * @param dacChannel - DAC channel.
 * @param outputRange - Output range of a DAC channel.
 *
 * @return None.
*******************************************************************************/
void AD5754R_RangeSelect(unsigned char dacChannel, unsigned char outputRange)
{
  Serial.printf("AD5754R_RangeSelect(%x, %x)...", dacChannel, outputRange );
  unsigned short registerData = 0;
 
  registerData |= outputRange;
  AD5754R_SetRegisterValue(AD5754R_REG_RANGE_SELECT,dacChannel,registerData);
}

/***************************************************************************//**
 * @brief Selects an option of Control Register.
 *
 * @param option - control function selected
 * @param bitValue - indicates a set or a clear of the following 
 *                   bits: SDO disable
 *                         CRL select
 *                         Clamp enable
 *                         TSD enable
 *
 * @return None.
*******************************************************************************/
void AD5754R_ControlFunction(unsigned char option, unsigned char bitValue)
{
  Serial.printf("AD5754R_ControlFunction(%x, %x)...", option, bitValue );
  unsigned char adrBits  = option & 0xF0;
  unsigned char dataBits = option & 0X0F;
  unsigned short oldControl = 0;
  unsigned short newControl = 0;
  if(adrBits == 0x01)
  {
    oldControl = AD5754R_GetRegisterValue(AD5754R_REG_CONTROL,0x01); 
    newControl = oldControl & ~(dataBits); 
    newControl = newControl | (bitValue * dataBits);
  }
  AD5754R_SetRegisterValue(AD5754R_REG_CONTROL,adrBits,newControl);
}

/***************************************************************************//**
 * @brief Read alert bits form Power Control Register.
 *
 * @param None.
 *
 * @return powerCtlStatus - Result of the Power Control Register read.
 *                          Contains alert bits: OCd, OCc, OCb, OCa and TSD.
 *                          Example: 0x01 - TSD is set
 *                                   0x05 - OCa and TSD are set
 *                                   0x3C - OCd, OCc, OCb, OCa are set.                             
 *
*******************************************************************************/
unsigned char AD5754R_ReadAlertBits(void)
{
  unsigned short powerCtlStatus = 0; 
   
  powerCtlStatus = AD5754R_GetRegisterValue(AD5754R_REG_POWER_CONTROL,
                                           0x00);
  powerCtlStatus = (powerCtlStatus >> 5);
  powerCtlStatus &= 0x003F;               // Only bits 5 to 0 are required.
  return ((unsigned char) powerCtlStatus);
}

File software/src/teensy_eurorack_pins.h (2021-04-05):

//
// Created by Moolet on 29/03/2021.
//

#ifndef TEENSY_EURORACK_TEENSY_EURORACK_PINS_H
#define TEENSY_EURORACK_TEENSY_EURORACK_PINS_H

#define TEENSY_EURORACK_PIN_ENC1_SW     4
#define TEENSY_EURORACK_PIN_ENC1_A      12
#define TEENSY_EURORACK_PIN_ENC1_B      24

#define TEENSY_EURORACK_PIN_ENC2_SW     9
#define TEENSY_EURORACK_PIN_ENC2_A      25
#define TEENSY_EURORACK_PIN_ENC2_B      28

#define TEENSY_EURORACK_PIN_ENC3_SW     10
#define TEENSY_EURORACK_PIN_ENC3_A      29
#define TEENSY_EURORACK_PIN_ENC3_B      30

#define TEENSY_EURORACK_PIN_POT1        14
#define TEENSY_EURORACK_PIN_POT2        15
#define TEENSY_EURORACK_PIN_POT3        41
#define TEENSY_EURORACK_PIN_POT4        22

#endif //TEENSY_EURORACK_TEENSY_EURORACK_PINS_H

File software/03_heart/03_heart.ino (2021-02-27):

#include "DrawingCanvas_st7735.h"
#include "ST7735_t3.h"
ST7735_t3 tft = ST7735_t3(1,2,3);
DrawingCanvas_st7735 canvas(tft);

uint16_t color = ST7735_WHITE;
uint16_t bgcolor = ST7735_BLACK;

void setup() {
    tft.initR(INITR_GREENTAB);
    tft.setRotation(3);

    float x_offset = 0.0f;
    float y_offset = 0.0f;
    tft.fillScreen(bgcolor);
    uint startTime = micros();
    canvas.drawLine(64.054863, 116.356781,
                    63.128590, 115.474579,
                    color, NoneAntialiased, NoneAntialiased  );

    canvas.drawCurve(0.1f,
                     63.128590, 115.474579,
                     22.372581, 77.539177,
                     11.566071, 64.482330,
                     11.566071, 43.309109,
                     color, NoneAntialiased, NoneAntialiased  );

    canvas.drawCurve(0.1f,
                     11.566071, 43.309109,
                     11.566071, 25.664846,
                     23.916372,  11.549276,
                     39.354259, 11.549276,
                          color, NoneAntialiased, NoneAntialiased  );

    canvas.drawCurve(0.1f,
                     39.354259, 11.549276,
                     52.013313, 11.549276,
                     59.114746, 19.665655,
                     64.054863, 26.017624,
                     color, NoneAntialiased, NoneAntialiased  );

    canvas.drawCurve(0.1f,
                     64.054863, 26.017624,
                     68.994995, 19.665657,
                     76.096413, 11.549277,
                     88.755478, 11.549277,
                     color, NoneAntialiased, NoneAntialiased  );

    canvas.drawCurve(0.1f,
                     88.755478, 11.549277,
                     104.193359, 11.549277,
                     116.543671, 25.664848,
                     116.543671, 43.309109,
                     color, NoneAntialiased, NoneAntialiased  );
    canvas.drawCurve(0.1f,
                     116.543671, 43.309109,
                     116.543671, 64.482330,
                     105.737152, 77.539169,
                     65.907410, 114.592377,
                     color, NoneAntialiased, NoneAntialiased  );

    canvas.drawLine(65.907410, 114.592377, 64.054863, 116.356781,
                    color, NoneAntialiased, NoneAntialiased  );

    uint stopTime = micros();

    Serial.printf("done in %i microseconds\n", stopTime - startTime);
}

void loop() {
    delay(100);
}

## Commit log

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2019-07-28 add bottom breakout board
    [bottom-breakout.brd, bottom-breakout.sch, uSD_extender_male.brd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]
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2019-09-08 move eagle files into their own folder
    [KnobsController.brd, KnobsController.sch]
2019-09-08 initial migration from eagle to kicad
    [KnobsController_1.sch, KnobsController_2.sch, KnobsController_v1.1.dsn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]
2019-09-08 Resolved all traces
    [KnobsController_v1.1.dsn, KnobsController_v1.1.kicad_pcb]
2019-09-08 added bourns rgb led PEL12T-4225s-S1024 step
    [Bourns PEL12T4225S-S1024.step, KnobsController_v1.1.kicad_pcb]
2019-09-08 fixed unconnected traces
    [KnobsController_v1.1.kicad_pcb]
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2019-09-21 redo migrate from eagle
    [KnobsController_v1.1.dsn, KnobsController_v1.1.kicad_pcb, enc.sch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]
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2019-09-22 dont forget drill holes
    [knobs-NPTH.drl, knobs-PTH.drl]
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2019-09-26 moved midi circuit to breakout board
    [MIDI.sch, TopBreakout.kicad_pcb, TopBreakout.sch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]
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2019-09-26 auto routed, not complete
    [TopBreakout.kicad_pcb]
2019-09-27 routed, ERC checks success
    [CS42448-CQZ.step, Conn_Wurth Electronics_61400413321.step, MIDI DIN 5 v7.step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]
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2019-09-28 knobs 3d + mainboard
    [Bourns PEL12T4225S-S1024.step, Mainboard.step, Panasonic_EVU-F2MFL3D14.step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]
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2019-10-21 tech drawings for assembly
    [assembly-details.FCStd]
2019-10-22 mainboard: add panel silkscreen to footprint of 6.5mm jack
    [Audio-in.sch, Audio-out.sch, Mainboard.kicad_pcb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]
2019-10-24 refine knobs board and panel design
    [Panel.step, knobs.kicad_pcb, panel.FCStd]
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2019-10-28 add microsd 3d model
    [TopBreakout.kicad_pcb]
2019-11-01 Gerber files for revision 1.4
    [Mainboard.kicad_pcb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]
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2019-11-10 fixed dimentions and step file color
    [Bourns PEL12T4225S-S1024-white.step, knobs.kicad_pcb]
2019-11-16 Mainboard: v1.5, changed diodes to 0805, corrected BCLK pin, moved LM340
    [Mainboard.FCStd, Mainboard.kicad_pcb, kryon-ver2.1-final_1.sch]
2019-11-16 knobs: better alignment of knobs
    [KnobsController.brd, KnobsController.sch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]
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2019-12-13 correction: tx, rx connected
    [enc.sch, knobs.kicad_pcb, knobs.sch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]
2019-12-14 v1.6 minor improvements to knobs- annotated SWD interface and connector to mainboard
    [knobs.kicad_pcb]
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2019-12-29 panel v1.6 corrections
    [panel.FCStd]
2020-01-01 v1.7: merge knobs and top breakout in to single board, remove fpc connector, replace with standard 0.1' pin header
    [enc.sch, knobs.kicad_pcb, knobs.sch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]
2020-01-01 revised order of pin headers to make routing easier
    [knobs.kicad_pcb]
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2020-01-01 breakout v1.7: corrections after DRC check
    [knobs.kicad_pcb]
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2020-01-05 correction: removed AVIN replaced with VIN
    [knobs.kicad_pcb, knobs_1.sch]
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2020-01-06 mainboard v1.7 minor changes
    [Mainboard.kicad_pcb]
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2020-01-10 silkscreen impr. & changed 100nF to 0.1uF
    [Mainboard.kicad_pcb, codec.sch]
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2020-01-18 front panel sketch v1.7
    [panel.FCStd]
2020-01-26 corrections to pcb,v1.7b
    [knobs.kicad_pcb]
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2020-02-17 CAD, tech drawings update
    [panel.FCStd]
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2020-03-09 100nF changed to 0.1uF
    [io_breakout-ver2.1_5.sch, knobs_1.sch, knobs_2.sch]
2020-03-09 updated 100nF to 0.1uF
    [knobs.kicad_pcb]
2020-03-09 fix version issue so kicad 5.1.5 can open pcb
    [knobs.kicad_pcb]
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2020-03-12 add missing schematics
2020-03-14 changed c6 to 0805, updates to footprints to simplify BOM
    [enc.sch, io_breakout-ver2.1_3.sch, io_breakout-ver2.1_5.sch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]
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2020-03-14 changed C26 from 4.7uf to 4.7uF
    [codec.sch]
2020-03-14 allow non-nightly builds to be able to open pcb and corrected project footprint path
    [Mainboard.kicad_pcb, knobs.kicad_pcb]
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2020-03-15 changed C26 from 4.7uf to 4.7uF, reduce number of distinct parts
    [Mainboard.kicad_pcb]
2020-03-17 corrected: unconnected trace
    [Mainboard.kicad_pcb]
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2020-03-18 fixed paths to 3d components and footprints
2020-06-15 v1.9 initial schematic, cleanup
    [1734592-8.stp, ACJS-MV35-5.step, ACJS-PH v28.step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]
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2020-06-19 single board, rough placement, abt to chop into 2 boards
    [teensy-eurorack.kicad_pcb, teensy-eurorack.sch]
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2020-06-20 silkscreen, corrections
    [AudioOut.sch, teensy-eurorack.kicad_pcb, teensy-eurorack.sch]
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2020-06-22 split into two boards
    [teensy-eurorack-breakout.kicad_pcb, teensy-eurorack-breakout.sch, teensy-eurorack.kicad_pcb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]
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2020-06-24 minor tweeks to breakout board
    [teensy-eurorack-breakout.kicad_pcb]
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2020-06-24 silkscreen improvments, gerbers, drc'ed
    [teensy-eurorack-breakout.kicad_pcb, teensy-eurorack.kicad_pcb]
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2020-07-22 changed schematic from A3 to A4
    [teensy-eurorack.sch]
2020-07-22 repositioned board to middle of page
    [teensy-eurorack.kicad_pcb]
2020-07-23 schematic A3 -> A4 page
    [teensy-eurorack-breakout.sch]
2020-07-23 recenter pcb in page
    [teensy-eurorack-breakout.kicad_pcb]
2020-07-25 connected DAC_SCK output (pin 19) to pin 31, corrected audio out 4 AGND net (was disconnected)
    [teensy-eurorack.kicad_pcb, teensy-eurorack.sch]
2020-07-25 corrected audio out 4 AGND (was disconnected)
    [teensy-eurorack.sch]
2020-07-25 corrected version number on schematic
    [teensy-eurorack-breakout.sch]
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2020-07-26 corrected TDM rx / tx pins
    [teensy-eurorack.sch]
2020-07-26 remove LRCLK, doesnt seemed to be used, connected LRCLKs to gnd on codec.
    [teensy-eurorack.sch]
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2020-07-27 add 3d model for acjs-mv5, updated footprint
    [ACJS-MV35-5.step]
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2020-07-27 Revert "recenter pcb in page"
    This reverts commit 40a09dfd2033d5d90cab69f8a1165afd283f11e8.
    [teensy-eurorack-breakout.kicad_pcb]
2020-07-27 corrected edge on breakout board
    [1734592-8.stp, ACJS-PH v28.step, Bourns PEL12T4225S-S1024-white.step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]
2020-08-09 correction: re-connect LRCLK to codec - as its required for TDM audio protocol
    [teensy-eurorack.sch]
2020-08-09 pcboard: re-connect LRCLK to codec, move hole for sd-extender cable further away from teensy, and move usb B headers up to avoid collision with SD-extender
    [teensy-eurorack.kicad_pcb]
2020-08-09 update revision in schematic
    [teensy-eurorack.sch]
2020-08-10 via sizes corrected
    [teensy-eurorack.kicad_pcb]
2020-08-10 gerbers updated with correct via size
2020-09-05 fix schematic errors and change breakout to 4 layer board
    [teensy-eurorack-breakout.kicad_pcb, teensy-eurorack-breakout.sch]
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2020-11-06 schematic: correct ADC_MISO to MISO1 (pin 39) and DA_SYNC to SPI1 CS (pin 38)
    [teensy-eurorack.sch]
2020-11-06 schematic: correct ADC_RANGE (pin 37)
    [teensy-eurorack.sch]
2020-11-06 schematic: corrections and updates
    [teensy-eurorack-breakout.sch, teensy-eurorack.sch]
2020-11-07 schematic, pcb changes for v2.0
    [teensy-eurorack-breakout.kicad_pcb, teensy-eurorack-breakout.sch, teensy-eurorack.kicad_pcb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]
2020-11-07 updated version to v2.0
    [teensy-eurorack-breakout.sch, teensy-eurorack.sch]
2020-11-07 mainboard: removed loopback for SPI clock as no longer needed
    [teensy-eurorack.kicad_pcb, teensy-eurorack.sch]
2020-11-15 corrections to breakout pcb
    [RotaryEncoder_Alps_EC11E-Switch_Vertical_H20mm.step, teensy-eurorack-breakout.kicad_pcb]
2020-11-28 schematic: change dac bypass caps to polar, correct polarity
    [teensy-eurorack-breakout.sch]
2020-11-29 pcb: update polatity of +-12v bypass caps
    [teensy-eurorack-breakout.kicad_pcb]
2020-11-30 schematic: adc to use same external voltage reference as dac
    [teensy-eurorack-breakout.sch]
2020-11-30 pcb: update from schematic and route as 4 layer board
    [teensy-eurorack-breakout.kicad_pcb]
2020-11-30 pcb: increase diameter of some via from 0.2mm to 0.25mm for jlcpcb
    [teensy-eurorack-breakout.kicad_pcb]
2020-12-01 pcb: update min via size to .45/.25 mm, routed as 4 layer
    [teensy-eurorack-breakout.kicad_pcb]
2020-12-22 soldermask clearance set to 0.05mm and minimum soldermask bridge to 0.2mm as per jlcpcb
    [teensy-eurorack-breakout.kicad_pcb]
2021-01-09 MAJOR: Correct polarity of +-12V on breakout boardgit add teensy-eurorack-breakout.sch
    [teensy-eurorack-breakout.sch]
2021-01-09 MAJOR: breakout PCB correction to polarity of +12V
    [teensy-eurorack-breakout.kicad_pcb]
2021-01-09 Minor pcb improvements: pins of DAC on same net should not bridge if posible as it looks unintentional solder bridge
    [teensy-eurorack-breakout.kicad_pcb]
2021-01-27 Breakout: changed from 4 layer to 2 layer; Mainboard: add serial daisy chain RX/TX to RX4/TX4
    [AudioIn.sch, AudioOut.sch, teensy-eurorack-breakout.kicad_pcb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]
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2021-01-30 mainboard pcb: spaced tracks out
    [teensy-eurorack.kicad_pcb]
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2021-02-13 st7735: change vcc,reset,backlight from 5v to 3v3
    [teensy-eurorack-breakout.kicad_pcb, teensy-eurorack-breakout.sch]
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2021-03-01 Tie LRCLK pin 20 to pin40 to sync DAC/ADC sampling w/ audio sampling
    [teensy-eurorack.sch]
2021-03-01 Mainboard PCB: Tie LRCLK pin20 to pin40 to sync DAC/ADC sampling w/ audio sampling
    [teensy-eurorack.kicad_pcb]
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2021-04-03 FIXED: add 1k pull-up resistor to MIDI rx pin
    [teensy-eurorack-breakout.kicad_pcb, teensy-eurorack-breakout.sch]
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2021-11-08 Update README.md
    https://forum.kicad.info/t/warning-avoid-all-links-to-kicad-pcb-org-use-kicad-org/31521
